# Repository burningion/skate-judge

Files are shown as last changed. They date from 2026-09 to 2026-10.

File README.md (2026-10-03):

# Judgy Skateboard

Record skateboard motion from an Adafruit LSM6DSO32 (accelerometer + gyro)
wired to an ESP32-S3 over STEMMA QT / Qwiic. Record webcam video in the web UI,
label makes, bails, and falls, and align webcam or phone footage using timestamped LED flashes.
The original live 3D orientation viewer is also included.

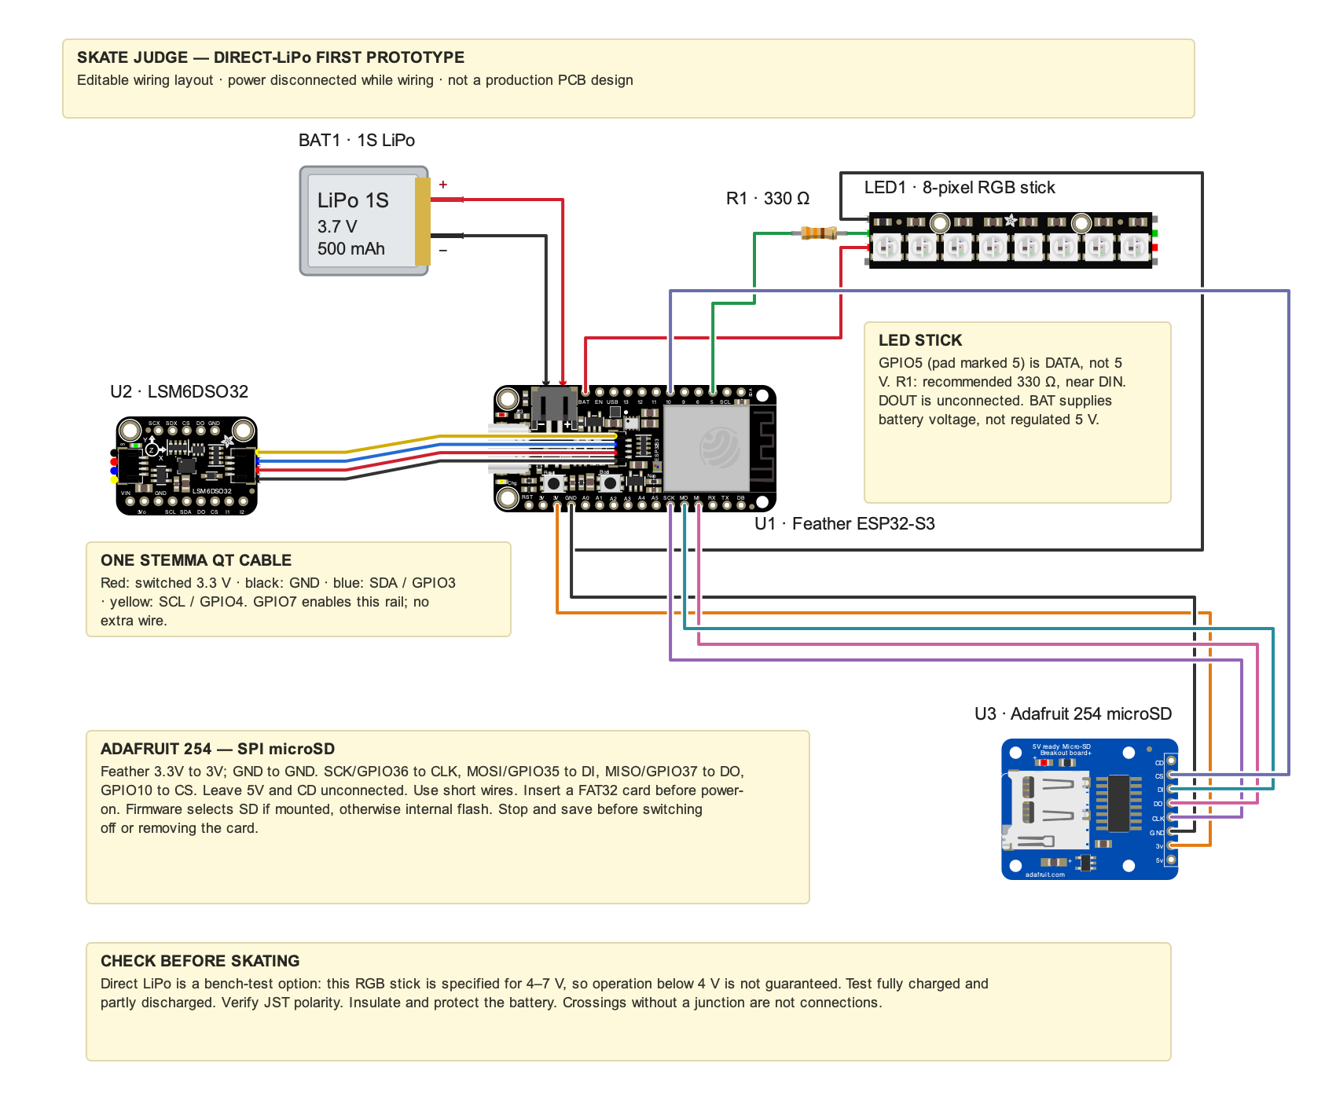
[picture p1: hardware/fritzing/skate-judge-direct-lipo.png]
hardware layout


This is the **data collection stage**: the review tool can suggest audio-based
pop/contact pairs for human review; it does not yet classify tricks, train
a model, or play automatic judgments. A board-mounted IMU measures the board's
motion, which does not always reveal whether the rider stayed on or fell.
Start with [your first dataset recording](docs/first-recording.md). The
[hardware and recording reference](docs/recording.md) covers wiring, file formats,
and the model plan.

[Research papers and reading notes](reference/README.md) cover skateboard IMU
trick recognition, landing-outcome limitations, and audio-feedback precedents.

```
firmware/imu_logger/   208 Hz sensor FIFO to SD or internal flash, timestamped LED sync
firmware/imu_stream/   legacy live stream for the orientation viewer
capture/onboard.py    onboard recording controls, verified download, recovery, CSV import
capture/session.py    recorder, human outcome labels, phone/video clock alignment
capture/dataset.py    collection progress and versioned datasets across reviewed sessions
capture/controls.html local webcam recording and countdown UI (--controls)
viz/imu_viz.py         pygame + OpenGL viewer: Mahony sensor fusion, calibration, 3D board with axes
viz/render_overlay.py transparent 3D skateboard + synchronized sensor/audio graphics for video editing
viz/trick_review.py    local video/audio review, onset pairs, editable boundaries, LED alignment
flash.sh               compile + upload with arduino-cli
flash-feather.sh        preset: Feather S3 8MB / no PSRAM, eight-pixel RGB stick on GPIO5
tests/                 sensor/video integrity, local HTTP, and webcam controller checks
```

## Your hardware and pinout

An [editable Fritzing wiring project](hardware/fritzing/README.md) is included,
with bundled parts and a preview of the direct-LiPo prototype.

A [parametric OpenSCAD enclosure](hardware/enclosure/README.md) includes PLA print
files, a screw-mounted deck base, a Velcro alternative, and a recessed LED mount
integrated into the enclosure's side.
Check the battery dimensions and mounting clearance before printing.

This setup uses the Adafruit Feather ESP32-S3 **8 MB flash / no PSRAM**, an
LSM6DSO32 IMU, a **3.7 V 500 mAh LiPo**, and an **eight-pixel SKC6812 RGB stick**.
For the first direct-LiPo bench test, wire with power disconnected:

| Connection | Destination |
| --- | --- |
| LiPo plug | Feather battery JST socket, with matching polarity |
| Feather `BAT` | Stick `5V` / `+` input |
| Feather `GND` | Stick `GND` |
| Feather header printed **5** (GPIO5) | Stick `DIN`, preferably through a 330 Ω resistor near `DIN` |
| Stick `DOUT` | Leave unconnected |
| Feather STEMMA QT socket | LSM6DSO32 STEMMA QT socket |

**The label “5” means GPIO5, not 5 volts or the fifth header position.**
The resistor is recommended protection on the data wire, not a strict requirement
or an LED brightness resistor. A short-wire bench test can omit it.

Adafruit documents direct LiPo power for short NeoPixel chains, but this stick's
listing specifies 4–7 V. Test visibility and correct colors as the battery runs
down before relying on it for sync; a regulated 5 V supply with a level shifter
is the fallback. See [power details and manufacturer sources](docs/recording.md#direct-lipo-wiring-for-the-first-test).

## First dataset recording

Flash the onboard logger, then initialize its unused storage once over USB:

```bash
./flash-feather.sh
uv run capture/onboard.py --board serial:auto initialize
```

Initialization refuses to erase a nonblank, unrecognized partition. The logger
keeps the preset's existing 1.5 MiB data partition; it does not repartition flash.

For battery operation, join **SkateJudge-XXXX** (password **skate-judge**), then:

```bash
uv run --offline capture/onboard.py record --rider rider-01 --board-name deck-01
```

Open the printed localhost URL. Enable microphone audio if you want audio onset
suggestions. **Record video + sync** starts webcam recording, waits for video
bytes to reach the laptop, starts onboard motion recording, checks its measured
rate, and only then begins the three-second LED countdown.

Acceleration and rotation use **nominal 208 Hz** acquisition through the sensor FIFO and are
saved on the **SD card when available**, with internal flash as the fallback
selected at boot. The page shows the storage destination, actual rates, errors,
and free space. The tested sensor measures about 196.5 Hz, consistent with its
factory clock calibration. Wi-Fi carries commands and status during capture; losing the connection
does not stop motion logging. Download happens after acquisition stops.

Repeat the sync countdown near the end, wait for the flash, then choose
**Stop & save video + board data**. Keep the tab and terminal open until both
are saved. The raw file is checksum-verified, imported into `samples.csv` and
`events.jsonl`, and retained on the board. Match the visible flashes in the
[review tool](docs/trick-review.md) to align video and motion.

Start with **one-minute test batches**. If using internal flash, its existing
partition holds only minutes; SD provides more capacity. Download and verify
each batch, then explicitly delete its onboard copy to reclaim space. See the
[first recording guide](docs/first-recording.md)
and [onboard storage/recovery reference](docs/onboard-recording.md).

For a USB bench check, use `--board serial:auto` before `record`. For a separate
phone camera, start that camera yourself and check the external-camera option
before syncing. Sessions are saved under `sessions/` and excluded from Git.

### Find and delete a test recording

Choose **Stop & save video + board data** and wait until saving finishes. The
terminal prints `Session: ...`, which is the laptop folder for that run. To
choose an easy-to-find folder before a USB test, use:

```bash
uv run --offline capture/onboard.py --board serial:auto record --output sessions/test-001
```

Use a new folder for each test. After saving, its `metadata.json` identifies the
run with `onboard_id`, its board storage with `onboard_storage` (`sd` or `flash`),
and its downloaded raw file with `onboard_raw_file`. The folder also contains
`samples.csv`, `events.jsonl`, and any video recorded through the webcam UI.

To inspect the board over USB, quit the saved recorder first to release the
serial port, then run these commands from the repository directory:

```bash
uv run --offline capture/onboard.py --board serial:auto status
uv run --offline capture/onboard.py --board serial:auto list
```

`status` shows the current storage destination in `storage` and remaining space
in `free_bytes`. `list` shows each saved run's `id`, `storage`, and `bytes` across
both mounted media. Match the ID to your session's `metadata.json`; the list is
not sorted by recording time. SD originals live at `/skate-judge/<id>.bin` on
the card. Downloading leaves the original on the board.

To remove one board copy, replace `<id>` and `<session>` below with your run's
32-character ID and laptop folder. Use `--storage flash` instead if that run's
storage is `flash`:

```bash
uv run --offline capture/onboard.py --board serial:auto delete "<id>" --storage sd \
  --downloaded "sessions/<session>/onboard-<id>.bin"
uv run --offline capture/onboard.py --board serial:auto list
```

The single-run `delete` command requires a downloaded raw file with a matching
ID and checksum. If you have not downloaded the run, retrieve it into a new folder first:

```bash
uv run --offline capture/onboard.py --board serial:auto download "<id>" --storage sd \
  --output sessions/recovered-test-001
```

Then use that folder's `onboard-<id>.bin` for `--downloaded`. To discard the
entire test, delete the board copy first, then move its laptop session folder
to Trash in Finder. Board deletion leaves the laptop files in place; deleting
the laptop folder alone does not reclaim board storage.

For Wi-Fi, join **SkateJudge-XXXX** and omit `--board serial:auto` from these
commands. The standalone `test-led` command creates no recording to clean up.

### Wipe all board recordings in one command

Stop any recording and quit the USB recorder, then run:

```bash
uv run --offline capture/onboard.py --board serial:auto wipe --yes
```

This permanently deletes **all recordings on both mounted SD and internal
flash**, including runs you have never downloaded. No download is required.
Laptop session folders, other SD card files, firmware, Wi-Fi credentials, and
pin settings are kept. The command works with the current logger firmware;
no reflash is needed.

Add `--storage sd` or `--storage flash` to clear only that medium. For Wi-Fi,
join **SkateJudge-XXXX** and omit `--board serial:auto`. `--yes` is required to
confirm deletion. The board must be idle; the command never stops a recording
for you. It reports each deletion and checks that the selected storage is empty
of recordings. If interrupted, rerun it to clear the remaining files. Storage
that is not mounted cannot be wiped.

## Review a recorded trick

The [audio/video review guide](docs/trick-review.md) explains onset detection,
editable pop/contact boundaries, and matching LED flashes to the sensor clock.
With FFmpeg installed, run:

```bash
uv run viz/trick_review.py sessions/<session>/webcam-<id>.webm
```

Open the printed local URL, match the LED flashes, then label attempts in the
same page. Choose the trick and outcome, or **Not a trick** for an onset false
positive; saving advances to the next suggestion. Labels save to `labels.jsonl`
with aligned sensor times. **Download saved labels** exports this clip's current
labels. Audio suggestions and unreviewed time remain unlabeled until you decide.

## Accumulate labeled sessions

Each session keeps its raw recordings and saved labels. After finishing or
correcting labels (for example, in `sessions/a7s-018`), run these commands from
the repository root to refresh the combined dataset from **all labeled
`sessions/a7s-*` directories**:

```bash
python3 capture/dataset.py status --labeled-only --allow-sample-gaps a7s-018
python3 capture/dataset.py build --labeled-only --allow-sample-gaps a7s-018 \
  --output datasets/a7s-v3
```

Choose an unused version directory each time (`a7s-v4`, `a7s-v5`, and so on).
Existing snapshots are immutable; saving labels does not refresh them. There is
no need to download or manually merge labels from the review UI.

`--labeled-only` skips sessions with missing or empty `labels.jsonl`, so unfinished
unlabeled recordings do not block the refresh. Omit it from `status` to inventory
every session. Labeled sessions still receive all alignment and sensor quality
checks; unreadable labeled sessions block the build.

`--allow-sample-gaps a7s-018` includes this complete recording despite its
`sample_gaps_over_10ms` flag: ten sample intervals were 10.1–10.5 ms, while
the typical interval was about 5.1 ms. Repeat this option on future refreshes
to keep including it. This exception applies only to the named session, only
when that is its sole onboard quality issue, and still excludes individual
windows with gaps over 30 ms, clipping, or other eligibility failures. The
source quality flag is retained; the report and manifest record the exception.
Omit the option for the original strict session policy. See the
[dataset guide](docs/dataset.md#accepting-a-session-with-small-sample-gaps) for details.

Check the printed counts and exclusions, then inspect the new snapshot's
`report.json` and `manifest.jsonl`. The manifest includes the latest revision of
every saved label and any exclusion reasons; `samples.csv` contains only eligible
IMU windows with session/rider IDs in the manifest. A saved label can be excluded
by a recording quality flag, stale alignment, or a bad sensor window. Investigate
these issues before using excluded labels for training; the export does not clear
quality flags.

See [dataset collection and export](docs/dataset.md) for exclusions, file formats,
and how to plan the first 100 attempts. Sessions and exports are local and
excluded from Git; back up the original session directories separately.

## One-time setup

```bash
brew install arduino-cli uv
arduino-cli core install esp32:esp32 --additional-urls https://espressif.github.io/arduino-esp32/package_esp32_index.json
```

The Adafruit LSM6DS library (plus BusIO and Unified Sensor) is installed into
`./.arduino` the first time `flash.sh` runs. NeoPixel builds also install
Adafruit NeoPixel there, so nothing touches your global Arduino sketchbook.

## Flash the board

For onboard capture with this Feather, use `./flash-feather.sh`. The generic
`./flash.sh` defaults to the legacy stream sketch used by the viewer.

Both scripts accept `--compile-only` to build without uploading.

The generic script builds for the `esp32s3` target with USB CDC on boot, so it
talks over the ESP32-S3's native USB port. It probes the usual STEMMA QT pin
pairs at startup and, for Adafruit Feathers, switches on the I2C power rail
first. It prints what it found:

```
I,LSM6DSO32 at 0x6A on SDA=3 SCL=4 (Adafruit Feather ESP32-S3 / Reverse TFT, I2C power on GPIO 7)
```

To try specific pins first: `IMU_SDA=3 IMU_SCL=4 IMU_POWER=7 ./flash.sh`.

For your **Adafruit Feather ESP32-S3, 8 MB flash / no PSRAM**, connect the
eight-pixel SKC6812 RGB stick's data circuit to the header marked **5** (GPIO5).
The preset selects the board, IMU wiring, Wi-Fi, and all eight pixels:

```bash
./flash-feather.sh --compile-only  # build first
./flash-feather.sh                 # upload once connected
```

All eight pixels flash white for 150 ms on `sync`, then turn off. Brightness
defaults to the maximum 255/255; override with `SYNC_LED_BRIGHTNESS`. For an RGBW stick,
use `SYNC_LED_RGBW=1 ./flash-feather.sh`.
See [stick wiring and power](docs/recording.md#eight-pixel-neopixel-stick)
before connecting it. Direct-LiPo wiring uses `BAT`; the Feather's `USB` pin
only supplies 5 V while USB is connected.

## Export transparent graphics for editing

After saving trick labels and matching the LED flashes, render a 3D skateboard
with synchronized onset, accelerometer, and gyroscope graphics:

```bash
uv run viz/render_overlay.py sessions/a7s-001 --video C0642.MP4 \
  --nose-axis x --up-axis=-z --width 1080 --height 1920
```

This writes one vertical transparent ProRes 4444 clip per attempt and PNG previews.
Add `--reel` for a combined reel.
If the board was level and still at every matched flash, add `--flat-syncs`
to use those moments as tilt and gyro-bias calibration references.
See [transparent overlays](docs/transparent-overlays.md) for slow motion,
mounting controls, timing, and editing instructions.

For isolated images comparing makes and bails, run
`uv run viz/plot_attempts.py sessions/a7s-001 --video C0642.MP4`.
This exports comparison sheets and one detailed PNG per attempt to
`sessions/a7s-001/plots/C0642-pop-contact/`, using shared scales and saved
pop/contact markers. Each detailed image includes accelerometer and gyro
magnitudes plus raw X/Y/Z traces.

## Run the viewer

The orientation viewer requires the legacy stream firmware. Switch explicitly:

```bash
SKETCH=firmware/imu_stream ./flash-feather.sh
```

Return to `./flash-feather.sh` and `capture/onboard.py` for onboard dataset capture.

```bash
uv run viz/imu_viz.py
```

The port is auto-detected; pass `-p /dev/cu.usbmodem101` to pick one, or
`--demo` to run without hardware. Keep the board still for the first two
seconds while the gyro bias is measured.

| Key | Action |
|-----|---|
| C | re-calibrate the gyro bias (hold the board still) |
| Z | zero the heading (yaw) |
| M | toggle fused (gyro + accel) and tilt-only (accel) modes |
| R | reset the filter, peaks, and clip counters |
| S | save a screenshot |
| drag / wheel | orbit / zoom the camera |
| Esc | quit |

Because the LSM6DSO32 has no magnetometer, heading (yaw) is integrated from the
gyro and slowly drifts; roll and pitch are pinned by gravity and do not. Press
`Z` whenever you want the heading re-zeroed.

The firmware runs the accelerometer at ±32 g and the gyro at ±2000 dps (about
2294 dps before the 16-bit readings actually saturate), so deck landings and
fast flips stay in range. The HUD shows the peak accel and gyro seen so far
against those limits, counts samples that reached full scale, and flashes a red
`CLIPPING` warning when one does. Press `R` to reset the peaks and counters.

## Serial protocol

One line per sample, targeted at 100 per second, accel in m/s^2 and gyro in rad/s:

```
D,<device_us>,<ax>,<ay>,<az>,<gx>,<gy>,<gz>,<temp_C>,<sequence>,<boot_id>
```

`device_us` is the 64-bit monotonic microsecond clock since boot. The sample
sequence is an unsigned 32-bit counter; the random eight-character hex boot ID
changes on reset. The viewer accepts these trailing fields. The recorder also
accepts the original nine-field format and unwraps its 32-bit microsecond clock.

At startup the board also prints `R,<accel_sat_ms2>,<gyro_sat_rads>`, the values
at which its raw readings saturate, which the viewer uses for its clipping
check. `I,...` lines are informational, `E,...` lines are errors. Sending `i`
asks the board to repeat its info lines.

Sending `s` requests a 150 ms pulse. Both LED edges produce:

```
S,<device_us>,<sync_id>,<edge>,<led_enabled>,<boot_id>
```

`edge=1` is the rising edge; `edge=0` is the falling edge. `led_enabled=0`
means only an event was recorded, with no physical flash. Each timestamp is taken
immediately before its LED write; it approximates the physical edge time.

With Wi-Fi enabled, UDP port 5050 accepts single-byte commands `i`, `?`, `s`,
and `k` (heartbeat). A recorder acquires a five-second lease by sending one
of these; packets go back to that client's address and port. The recorder
renews every two seconds. One client owns the lease at a time. UDP can lose
packets; sequence gaps and timing gaps are saved for quality review.

## Checks

```bash
python3 -m unittest discover -s tests -v
node --test tests/test_webcam.mjs tests/test_trick_review.mjs tests/test_storage.mjs tests/test_battery.mjs
./flash-feather.sh --compile-only
./flash.sh --compile-only
SKATE_WIFI=1 ./flash.sh --compile-only
```

## Troubleshooting

- **No `/dev/cu.usbmodem*` after plugging in.** On Apple Silicon a new accessory
  first needs the "Allow accessory to connect" approval. Other apps that open
  every USB device (Chrome's WebUSB, Spotify) can also grab the port before the
  serial driver does; unplugging and replugging the board usually fixes it.
- **`./flash.sh` fails while "Connecting..."** The reset into the bootloader can
  re-enumerate the USB device and kill the port node; the script already retries
  once, otherwise replug and rerun.
- **`E,no LSM6DSO32 found`** Check the STEMMA QT cable, and if your board is not
  in the sketch's candidate table, pass the pins explicitly with `IMU_SDA` /
  `IMU_SCL` (and `IMU_POWER` if the port has a power-enable pin).

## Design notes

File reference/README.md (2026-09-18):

# Skateboard IMU research

Selected for **Judgy Skateboard**: a board-mounted accelerometer and gyroscope,
video-reviewed landed/failed attempts, and eventual spoken feedback after a
missed trick. Sources and download availability checked **2026-09-18**.

The closest hardware match is **Groh et al. (2015)**. Read its **2017 follow-up**
for failed attempts and false event detections, **Anlauff et al. (2010)** for
skateboard-triggered audio, and **Scholz et al. (2026)** for independent validation.

The central distinction is between **detecting an attempt**, **naming the trick**,
and **judging whether the rider landed and maintained control**. The reported
trick-recognition scores below do not establish make/bail/fall accuracy for this
project. In particular, an impact can locate board contact without proving that
the rider stayed on.

## Reading list and local copies

| Priority | Paper | Why it matters here | Copy |
| --- | --- | --- | --- |
| 1 | Groh et al., 2015 | Board-mounted six-axis IMU at 200 Hz; event detection and simple classifiers | [PDF](groh-2015-imu-based-trick-classification.pdf) |
| 2 | Groh et al., 2017 | Larger study includes incorrect attempts, bails, and false detections | Reference below; no public full PDF verified |
| 3 | Anlauff et al., 2010 | Real skateboard controls a game with audio feedback | Public author PDF linked below; download timed out |
| 4 | Scholz et al., 2026 | Independent field validation; exposes the gap between event detection and trick classification | [PDF](scholz-2026-skateboard-imu-validation.pdf) |
| 5 | Abdullah et al., 2021 | IMU signal classification with published data and code | Open-access links below; download unavailable from this environment |
| 6 | Ibrahim et al., 2020 | Small, interpretable feature-based baseline | Public university PDF linked below; download timed out |
| 7 | Corrêa et al., 2017 | Accelerometer-only neural-network approach, evaluated on synthetic signals | [PDF](correa-2017-accelerometry-machine-learning.pdf) |

The three saved PDFs are unmodified source files. Their original copyright and
license notices remain in the documents. A missing local copy does not necessarily
mean a paper is paywalled: the table distinguishes missing public full text from
download failures.

## 1. IMU-based Trick Classification in Skateboarding

**Benjamin H. Groh, Thomas Kautz, Dominik Schuldhaus, and Bjoern M. Eskofier.
2015.** KDD Workshop on Large-Scale Sports Analytics, Sydney, Australia.

[Local PDF](groh-2015-imu-based-trick-classification.pdf) ·
[University-hosted source PDF](https://www5.cs.fau.de/Forschung/Publikationen/2015/Groh15-ITC.pdf) ·
[Author's publication list](https://www.mad.tf.fau.de/person/benjamin-groh/)

- **Setup:** Board-mounted accelerometer/gyroscope at 200 Hz, ±16 g and
  ±2000 degrees/s; seven skateboarders, six tricks, and video/expert annotations.
  Our nominal 208 Hz logger is similar, with a wider ±32 g range.
- **Method:** Acceleration-energy thresholds locate impacts. Features span one
  second before through half a second after contact; several simple classifiers
  predict trick identity.
- **Evidence:** 94.2% event sensitivity and 97.8% best classification accuracy with
  leave-one-subject-out evaluation. Classification excluded false event detections;
  that score measures trick identity, not landing outcome.
- **Use here:** Sections 2.3–2.6 provide an event/feature baseline. Record mounting
  axes and stance: their preprocessing normalizes regular/goofy signals.

## 2. Classification and visualization of skateboard tricks using wearable sensors

**Benjamin H. Groh, Martin Fleckenstein, Thomas Kautz, and Bjoern M. Eskofier.
2017.** *Pervasive and Mobile Computing* **40**, 42–55.
DOI: [10.1016/j.pmcj.2017.05.007](https://doi.org/10.1016/j.pmcj.2017.05.007).

[Publisher article and preview](https://www.sciencedirect.com/science/article/pii/S1574119217302833)

- **Setup:** One skateboard-mounted inertial–magnetic unit; 11 skateboarders,
  11 tricks, and 905 performances, including correct and incorrect executions
  and bails.
- **Evidence:** The event detector found 872 of 905 attempts, with 431 false
  detections: 96.4% recall and 66.9% precision. Subsequent classification includes
  a rest class to reject non-trick events. The advertised 89.1% trick-classification
  accuracy concerns correctly performed tricks.
- **Use here:** This is the strongest match for collecting failures and background
  alongside makes. It illustrates why a high-recall impact detector needs a second
  stage before triggering a roast. The reported recognition result does not tell
  us how accurately our make/bail/fall labels can be predicted.
- **Limit/access:** Its nine-axis hardware includes a magnetometer that our
  LSM6DSO32 lacks. These notes use the publicly available abstract and preview;
  no public complete PDF was verified. The publisher offers institutional access
  or PDF purchase.

## 3. A Method for Outdoor Skateboarding Video Games

**Jan Anlauff, Erik Weitnauer, Alexander Lehnhardt, Stefanie Schirmer,
Sebastian Zehe, and Keywan Tonekaboni. 2010.** *Proceedings of the 7th International
Conference on Advances in Computer Entertainment Technology (ACE '10)*, 40–44.
DOI: [10.1145/1971630.1971642](https://doi.org/10.1145/1971630.1971642).

[Public author PDF at Bielefeld University](https://www.techfak.uni-bielefeld.de/ags/ami/publications/media/AnlauffWeitnauerLehnhardtSchirmerZeheTonekaboni2010-AMF.pdf)

- **Setup:** The Tilt'n'Roll prototype connects a sensor-equipped real skateboard
  to a mobile game. It collects acceleration, angular velocity, and foot-pressure
  information at approximately 70 Hz, and uses linear discriminant analysis for
  Ollie, Ollie 180, and a no-trick class.
- **Use here:** An unusually close precedent for the product idea: detected tricks
  drive game events, and the rider receives progress information through audio.
  Its pressure channel is also relevant if board motion alone proves ambiguous
  about whether the rider is still aboard.
- **Limit/access:** Its extra pressure sensors and small trick vocabulary differ
  from our setup; it does not validate make/bail/fall classification. The public
  author copy is indexed, but university and publisher downloads timed out here.

## 4. Validity of a Commercially Available Inertial Measurement Unit for Artificial Intelligence-Based Trick Detection and Kinematic Performance Assessment in Skateboarding

**Birte Scholz, Niklas Noth, Maren Witt, and Olaf Ueberschär. 2026.**
*Sensors* **26**(8), 2537.
DOI: [10.3390/s26082537](https://doi.org/10.3390/s26082537).

[Local PDF](scholz-2026-skateboard-imu-validation.pdf) ·
[Open-access article](https://www.mdpi.com/1424-8220/26/8/2537) ·
[Source PDF](https://mdpi-res.com/d_attachment/sensors/sensors-26-02537/article_deploy/sensors-26-02537.pdf)

- **Setup:** Independent Spinnax Freak validation with 23 skateboarders and
  reference measurements including video and light barriers.
- **Evidence:** Ollie/Kickflip event detection outperformed trick naming; airtime
  and other motion measurements showed substantial errors.
- **Critical limitation:** Section 2.3 explains that failed attempts were repeated
  or abandoned; all documented tricks were successfully landed. This does not
  validate bail/fall detection. The classifier is proprietary.
- **Use here:** Validate event detection, trick identity, and outcome separately
  against reviewed video before using a prediction to trigger audio.

## 5. The classification of skateboarding tricks via transfer learning pipelines

**Muhammad Amirul Abdullah, Muhammad Ar Rahim Ibrahim, Muhammad Nur Aiman
Shapiee, Muhammad Aizzat Zakaria, Mohd Azraai Mohd Razman, Rabiu Muazu Musa,
Noor Azuan Abu Osman, and Anwar P.P. Abdul Majeed. 2021.**
*PeerJ Computer Science* **7**, e680.
DOI: [10.7717/peerj-cs.680](https://doi.org/10.7717/peerj-cs.680).

[Open-access article](https://peerj.com/articles/cs-680/) ·
[PubMed Central full text](https://pmc.ncbi.nlm.nih.gov/articles/PMC8384043/) ·
[Publisher PDF](https://peerj.com/articles/cs-680.pdf) ·
[Code supplement](https://doi.org/10.7717/peerj-cs.680/supp-1) ·
[Dataset supplement](https://doi.org/10.7717/peerj-cs.680/supp-2)

- **Setup/method:** Six skateboarders perform five trick types. The six IMU
  channels become raw-signal images or continuous-wavelet-transform images;
  pretrained CNNs extract features for an optimized SVM. These are images of
  sensor signals, not camera frames.
- **Use here:** Compare learned representations with time-domain features. Raw
  data and code supplements support inspecting the collection format and
  reproducing a trick-identity baseline.
- **Limit/access:** Trick classes differ from our outcome classes. Check the data
  and evaluation splits before reuse; results do not establish failed-attempt
  recognition. Public PDF hosts timed out or blocked retrieval here. Supplements
  are linked, not imported into training sessions.

## 6. The Classification of Skateboarding Trick Manoeuvres: A K-Nearest Neighbour Approach

**Muhammad Ar Rahim Ibrahim, Muhammad Amirul Abdullah, Muhammad Nur Aiman
Shapiee, Mohd Azraai Mohd Razman, Rabiu Muazu Musa, Muhammad Aizzat Zakaria,
Noor Azuan Abu Osman, and Anwar P.P. Abdul Majeed. 2020.** In *Enhancing Health
and Sports Performance by Design*, Lecture Notes in Bioengineering, 341–347.
DOI: [10.1007/978-981-15-3270-2_36](https://doi.org/10.1007/978-981-15-3270-2_36).

[University repository record](https://umpir.ump.edu.my/id/eprint/33630/) ·
[Public PDF](https://umpir.ump.edu.my/id/eprint/33630/1/MAR1.pdf)

- **Setup/method:** One experienced amateur skateboarder performs five trick
  types on an IMU-equipped board. Features include mean, skewness, kurtosis,
  peak-to-peak, RMS, and standard deviation of acceleration and angular velocity.
  The best tested kNN configuration achieved 85% trick-classification accuracy.
- **Use here:** A compact feature list for an inexpensive first baseline before
  trying larger neural models.
- **Limit/access:** A single-rider preliminary study cannot establish generalization
  across riders, boards, or surfaces, and its target is trick identity. The
  university advertises a public PDF, but its download host timed out here.

## 7. Development of a skateboarding trick classifier using accelerometry and machine learning

**Nicholas Kluge Corrêa, Júlio César Marques de Lima, Thais Russomano, and
Marlise Araujo dos Santos. 2017.** *Research on Biomedical Engineering*
**33**(4), 362–369.
DOI: [10.1590/2446-4740.04717](https://doi.org/10.1590/2446-4740.04717).

[Local PDF](correa-2017-accelerometry-machine-learning.pdf) ·
[Journal record](https://www.rbejournal.periodikos.com.br/article/doi/10.1590/2446-4740.04717) ·
[arXiv record](https://arxiv.org/abs/2005.04186) ·
[Source PDF via arXiv export](https://export.arxiv.org/pdf/2005.04186)

- **Method:** Feed-forward neural networks classify five trick types using
  modeled acceleration signatures, with separate networks for individual axes.
- **Critical limitation:** The study uses **543 artificial axis signals representing
  181 simulated tricks**, not a dataset of 543 real attempts. Its reported scores
  therefore do not demonstrate recognition of actual makes, bails, or falls.
- **Use here:** Background on accelerometer signatures, preprocessing, and an
  accelerometer-only comparison. Prioritize real, reviewed recordings for our
  outcome model. Retaining gyro channels also allows an accelerometer-only versus
  six-axis comparison on the same held-out sessions.
- **Version:** The journal paper is from 2017; its arXiv deposit is from 2020.
  The downloaded PDF contains the journal article and its CC BY notice.

## Implications for this repo

These are proposed experiments, not claims that the papers validated our model.
They align with the existing [model plan](../docs/recording.md) and
[video-labeling workflow](../docs/trick-review.md).

1. **Keep outcome and trick identity separate.** Preserve `make`, `bail`, `fall`,
   `unknown`, and `background`. A binary landed/not-landed target can later map
   `make` versus `bail`/`fall`; do not silently map unknown or background to a miss.
2. **Keep the roll-away.** Pop/contact markers locate the action, while the full
   attempt window must include enough aftermath to judge control. Compare contact
   windows with windows that include post-contact motion.
3. **Measure the whole trigger pipeline.** Evaluate missed attempts and false
   roasts during continuous skating, including pushing, carrying, dropping the
   board, and ordinary rolling. Report outcome precision/recall, false triggers
   per minute, and delay after the outcome.
4. **Hold out sessions and riders.** Avoid mixing neighboring windows from one
   recording across training and test sets. Preserve mounting orientation, board,
   stance, surface, and sensor-quality metadata to investigate errors.
5. **Start with a small baseline and an uncertain result.** Compare simple
   acceleration/gyro features before heavier models. Tune the failure threshold
   and cooldown on validation sessions; ambiguous board motion should be allowed
   to produce no audio response.

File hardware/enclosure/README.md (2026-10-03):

# PLA enclosure for Judgy Skateboard

Open **[skate-judge.scad](skate-judge.scad)** in **OpenSCAD 2021.01 or newer**.
This is a printable prototype for the project's Feather ESP32-S3, LSM6DSO32,
500 mAh LiPo, Adafruit 254 microSD breakout and an eight-pixel sync stick mounted
**inside the long side wall**.
It needs a physical fit check
and progressive riding trials; CAD checks do not establish impact survival.

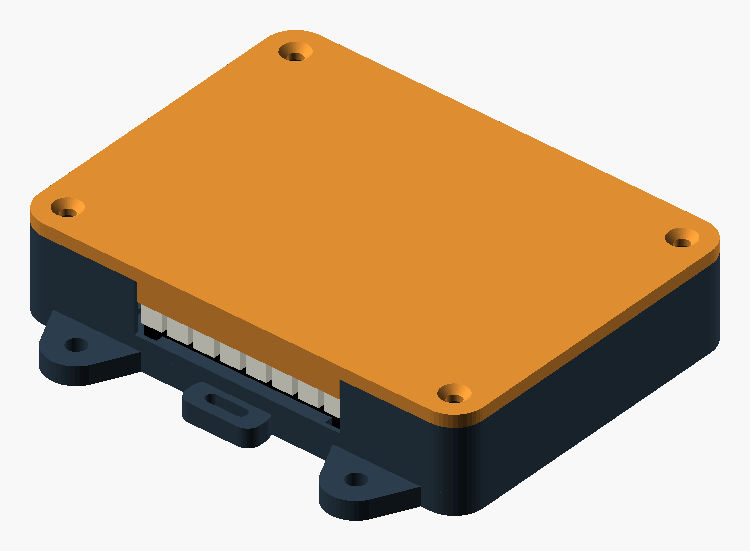
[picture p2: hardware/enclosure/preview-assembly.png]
Enclosure with recessed side-facing LEDs


**Revision 8 — 2026-10-03, heat-set inserts for the lid.** Both bases now use
four top-loaded **M3 × 4 × 5 mm inserts** in place of the side-loaded hex nuts.
The user confirmed the Jouth size as **M3 thread, 4 mm length,
5 mm outside diameter**. A Jouth recommended hole size was not available;
check the printed fit with the coupon before printing the base.
The starting bore is **4.6 mm diameter × 5 mm deep**, with a **0.2 mm entry bevel**
opening to 5.0 mm. Install inserts flush with the boss tops. The existing 12 mm
boss diameter leaves 3.5 mm of plastic radially around a 5 mm insert; the side
nut channels are filled in. A **3.4 mm screw-tip clearance bore extends 10 mm
below the boss top**, so existing M3 × 12 mm countersunk screws retain nominal
1 mm tip clearance with the 3 mm lid. M3 × 8 mm screws also reach the full insert.

**Reprint only the base**: [standard base](exports/base.stl) or
[Velcro base](exports/base-velcro.stl). The lid geometry and hole centers are
unchanged. Print the revised **[fit coupon](exports/fit-coupon.stl)** first:
its three full-height bosses have labeled **4.4 / 4.6 / 4.8 mm** insert bores,
the same depth, bevel and screw relief as the base, and separate M2 pilot tests.
Use the same filament, orientation and wall settings as the base. Choose the
fit that heat-sets squarely and holds without splitting or spinning after cooling;
change `lid_insert_bore_diameter` and rebuild if the center bore is not the best
fit. A CAD clearance check does not establish heat-set retention.

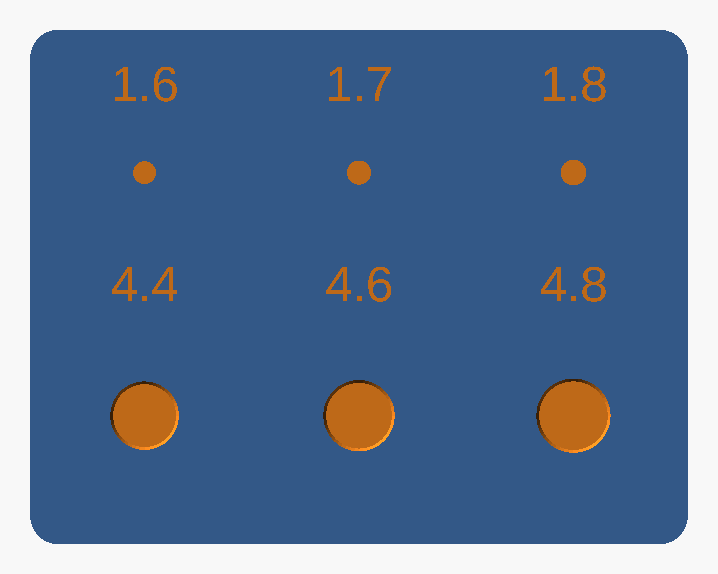
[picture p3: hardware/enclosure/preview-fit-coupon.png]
Insert bore and M2 pilot fit coupon


**Revision 7 — 2026-10-02, power-switch cutout beside USB.** Both bases now
have a **13.5 mm wide × 8.4 mm high** rectangular opening in the **x=0 short
wall**, on the same side as USB. This uses the measured **13.27 × 8.18 mm**
KCD11-101 style switch body with **0.23 × 0.22 mm total clearance**; no further
fit allowance is added. The opening is centered at **Y=50, Z=11.5 mm**, spanning
Y=43.25–56.75 and Z=7.3–15.7 mm. It leaves **7.82 mm of wall between the USB
and switch openings**, and 4.3 mm of material above and below the opening
between the floor and rim. **Only the base needs reprinting**; use the refreshed
[base](exports/base.stl) or [Velcro base](exports/base-velcro.stl). The lid still fits.

The switch inserts through the existing **3 mm wall**. Check the actual snap
clips, bezel, body depth, terminals and insulated wire bends against the battery
tray/strap anchor before assembly; only the supplied body cross-section is known.
The cutout adds a **13.5 mm roof bridge** to the base, so inspect that bridge in
the slicer and check the printed opening with your switch.

**Revision 6 — 2026-09-26, preserve the installed IMU orientation.** The user
confirmed that the IMU extends from its two screws toward the SD board, with
components facing the lid. In that orientation, the old screw positions put
the IMU into the SD mounting posts. R6 moves both IMU posts **12.7 mm toward
the LED window**: centers are now **(76.54, 19.54)** and **(96.86, 19.54)**,
instead of Y=32.24. Slide the physical IMU toward the LEDs without turning it.
Its two screws now sit on the LED side of its PCB; the PCB extends toward SD.
This corrects the previous drawing's orientation assumption.

The IMU posts remain **4 mm high** and the SD posts **7 mm high** above the
floor. There is **4.22 mm nominal separation between the PCB outlines**.
Changing heights is unnecessary; lowering SD would reduce the card-removal
clearance above the battery. **Only the base needs reprinting**; the lid and
SD mounting sample are unchanged. Use the refreshed [base](exports/base.stl)
or [Velcro base](exports/base-velcro.stl). The current R8 exports retain this layout.

Existing recordings remain in their original sensor axes. Keeping the same
physical orientation avoids a new axis mapping, but translating the sensor can
change the acceleration measured during rotations. Record the R6 mount revision
and 12.7 mm position shift alongside subsequent sessions; do not overwrite old
session mounting descriptions or rotate their raw samples to match a CAD image.
If the sensor is physically rotated in a future revision, retain the originals
and apply the measured sensor-to-deck rotation to both acceleration and gyro
during analysis. The existing overlay tools support explicit nose/up axis mapping.

**Revision 5 — 2026-09-26, screw-mounted microSD breakout.** Four 7 mm-high posts
secure the Adafruit 254 board beside the battery, with a separate wire tie point.
The enclosure dimensions stay the same. **Reprint only the base if you already
have an R3/R4 lid**; the R4 lid geometry is unchanged. The SD card slides toward
the battery for removal with the lid off. Its path is raised above the assumed
5 mm-thick cell; keep the battery strap and wires out of that path.

Print the [SD mounting sample](exports/sd-fit-base.stl) first to check all four
holes and your screws. It is **33.75 × 27.4 × 10 mm**, with the same post heights
and pilots as the full base. Use four **M2 × 5 mm screws suitable for plastic**,
with heads no larger than **4 mm diameter × 2 mm high**. This is for the
Adafruit 254 hole pattern (20.32 mm square); check your actual board against it.
The sample checks mounting fit, not the complete wiring or card-removal path.

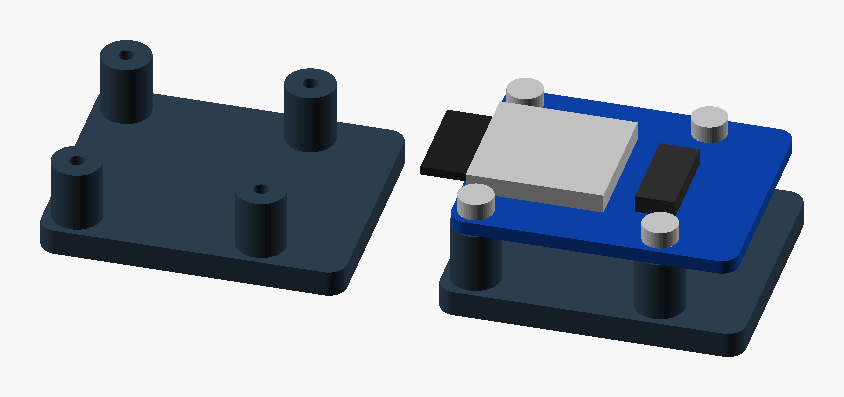
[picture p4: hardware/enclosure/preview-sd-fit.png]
MicroSD mounting posts and compact fit sample


**Revision 4 — 2026-09-15, DIN 7991 M3 flat-head lid screws.** All four lid holes
now have a **6.4 mm exterior opening, 90° included bevel and 1.5 mm recess depth**,
with the existing 3.4 mm shaft clearance. This leaves 1.5 mm of the 3 mm lid
beneath each bevel. DIN 7991 M3 heads are 6 mm across with a 90° bevel
([supplier drawing](https://belmetric.com/content/A-PDF_Drawings/SF3X6SS.pdf));
the opening adds 0.4 mm of diameter for printed fit. Check seating with your
actual screws; diameter and angle remain adjustable. The R4 lid fits the R3
base, so only the lid needs reprinting for this change.

**Revision 3 — 2026-09-08, fixes from the first physical print.** The previous
lid preview reflected the printed part instead of rotating it into place. This
hid the reversed position of its asymmetric wall-closing tabs. The lid STL now
accounts for the physical flip; neither the preview nor the fit check reflects
the printed lid into place.

The LED PCB slides down into a channel from the open top. The screwed-on lid
retains it; the eight pixels face outward through a recessed side opening.
Both ends now have actual **open-top through-slots for soldered leads**. Rear
guides are moved away from the solder zones, and the lid locates the PCB's
unsoldered upper corners. It leaves 0.8 mm above the board instead of 0.3 mm.

Print the [LED fit sample base](exports/led-fit-base.stl) and
[matching sample lid](exports/led-fit-lid.stl) first, and try your **soldered**
stick. These reproduce the entire holder and its lid features in a
**63.1 × 13 mm footprint**; hold the lid seated by hand. They do not test the
USB tab or full enclosure screw alignment. When upgrading from R2, print **both
the revised full base and lid**. R3/R4 lid corner locators occupy the old end-stop
positions; do not mix R3/R4 parts with the unmodified R2 base/lid.

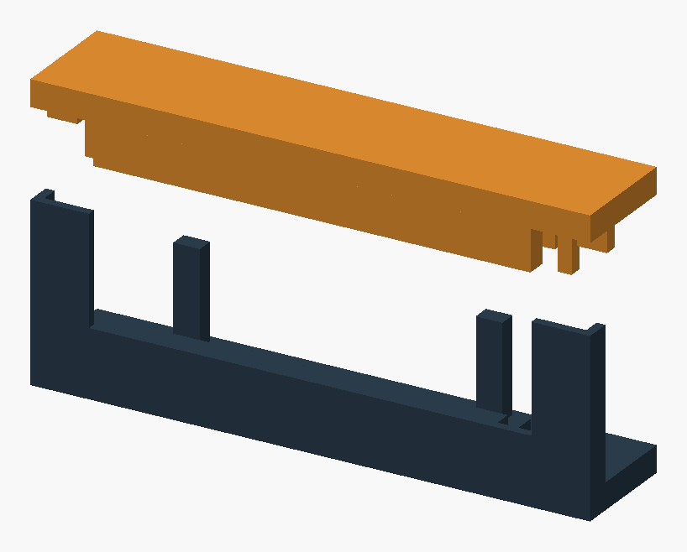
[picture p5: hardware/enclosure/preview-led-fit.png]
Small LED holder and matching lid test pieces


## Mounting choice

**Use a rigid deck mount for motion recording.** The default base has four broad
4.5 mm-thick lugs with 4.5 mm clearance holes, a flat deck-facing back, and two
tether slots. The lid faces away from the deck and is removable while mounted.
Nominal shell dimensions are **108 × 80 × 23 mm**, excluding screw heads;
the lugs increase the footprint to **108 × 106 mm**. Place its long axis along
the deck, inboard of a truck, with the LED side facing the camera and clearance
checked on your actual board. Confirm that the deck overhang does not hide the
LEDs at the intended camera height; a side window alone does not establish visibility.
No deck curvature, truck geometry, or wheel sweep was supplied.

| Attachment | Use with this model |
| --- | --- |
| Deck screws/bolts | Preferred for rigid IMU coupling. Four M4 through-bolts, washers and locking nuts through suitable deck holes and the lugs. Hole centers form a 68 × 92 mm rectangle. Choose length for the measured deck, 4.5 mm lugs, washers and full nut engagement. This is a new mounting pattern, **not truck-bolt spacing**. |
| Adhesive hook-and-loop | Use `base-velcro.stl` or the standard base. Its flat back accepts two roughly 20 × 60 mm strips. The earless version is 108 × 94 mm including tether lugs. Use a secondary tether; check tape compatibility with the deck finish and leave tether slots clear. Hook-and-loop compliance can introduce motion artifacts, so compare a recording against a rigid mount. |
| PLA truck snap | Not selected. A stressed snap is a poor match for brittle PLA under repeated skate impacts. The hanger also steers relative to the deck. A future truck adapter should attach to the fixed baseplate using measured geometry and appropriate hardware, and use a tougher material; this design does not alter truck hardware or add a PLA riser to that joint. |

The PLA decision is an engineering judgment based on [Prusa's material guidance](https://help.prusa3d.com/article/pla_2062): PLA is brittle, has weak impact/layer resistance,
and can deform above about 60 °C. This enclosure uses thick walls and broad lugs,
with no spring clips or constantly flexed latches. Keep it out of hot cars and
direct heat. For a durable riding version, reconsider the material and validate
the printed parts rather than relying on PLA geometry alone.

Do not use ordinary short wood screws as an assumed universal skate-deck mounting
solution: the deck thickness, condition, screw penetration and placement need to
be checked first. Do not compromise existing truck holes or crush the deck with
fasteners. Match a curved deck using fitted **rigid** shims under the lugs; do not
pull a flat enclosure into the concave with screw torque. The flat Velcro back
likewise needs enough actual contact area on your deck.

## Parts to print

| STL | Quantity | Print orientation |
| --- | --- | --- |
| [base.stl](exports/base.stl) | 1 | Flat deck-facing back on bed, cavity up |
| [base-velcro.stl](exports/base-velcro.stl) | Alternative to base | Same; ears omitted, tether lugs retained |
| [lid.stl](exports/lid.stl) | 1 | Flat exterior face on bed, guide ribs up |
| [fit-coupon.stl](exports/fit-coupon.stl) | 1 first | Flat back on bed, insert bosses upward; 46 × 36 × 20 mm |
| [led-fit-base.stl](exports/led-fit-base.stl) | 1 first | Flat bottom on bed, slot upward |
| [led-fit-lid.stl](exports/led-fit-lid.stl) | 1 first | Flat exterior on bed, tabs upward |
| [sd-fit-base.stl](exports/sd-fit-base.stl) | 1 first | Flat bottom on bed, posts upward |

Exported files already have those orientations and use millimeters. The LED mount
fits inside the existing shell footprint. `layout` is for visual inspection;
arrange individual STLs for your printer's bed.
Do not print `assembly` or `exploded`: those views include illustrative electronics.

Start with a 0.4 mm nozzle, 0.20 mm layers, **5 perimeters**, 6 top/bottom layers,
and 35–45% gyroid infill. Use solid local infill around lugs, lid bosses and PCB
posts if the slicer leaves voids there. Use your filament's calibrated PLA profile.
The R8 insert bores open upward and remove the old nut-pocket roof bridges.
Strap/wire-anchor tunnels still require approximately 8.4 mm bridges, and the
switch opening has a 13.5 mm roof bridge. **PrusaSlicer 2.9.6 flagged "Floating
bridge anchors" on earlier bases** during the 0.20 mm/5-perimeter slice check.
Support-free printing of R8 is unverified: inspect those remaining spans layer
by layer, and test a cropped anchor section or paint removable local supports
with accessible removal paths. The insert coupon reproduces the boss depth and
bores, but does **not** test the strap or switch bridges.
The LED window is open to the rim in the base; its upper frame prints as part of
the lid. The rear LED guides rise from the floor, inboard of the solder zones.
The end wire slots are open to the top, so they introduce no roof bridges.
The 0.3 mm lid clearance is **per side**. Deburr openings that contact wires.
The countersink openings face the bed and taper inward as the lid prints.
The default lid has no markings. Optional `lid_markings=true` engraves the exterior;
that version triggered a long-bridge warning in PrusaSlicer and is not the
supplied print default.

## Hardware and assembly

- Four **M3 heat-set inserts, 4 mm long × 5 mm outside diameter**, and four
  **DIN 7991 M3 flat-head machine screws**. Use **8 mm overall length**, or reuse
  the existing **12 mm** screws after checking tip clearance. Countersunk screw
  length includes the head. With a flush head and the 3 mm lid, an 8 mm screw
  projects 5 mm into the boss and a 12 mm screw projects 9 mm; the blind relief
  ends at 10 mm. Smaller heads can seat below flush and move the tip deeper.
  Confirm full insert engagement and that the screw clamps the lid before it
  bottoms. Heat-set inserts squarely from above, **flush with the boss top**,
  with electronics and battery removed. Follow your insert/filament installation
  guidance, test on the coupon, and let the inserts cool before threading screws.
  Clear any raised plastic so the lid seats flat. No hex nuts are used in R8.
  Snug by hand; do not torque a metal fastener hard against PLA. Recheck after
  early rides.
- Ten **M2 × 5 mm screws suitable for plastic pilots**: four for the Feather,
  two for the IMU, four for the SD breakout. Nominal pilot is 1.7 mm, blind,
  with 4 mm standoffs for the Feather/IMU and 7 mm for SD.
  Test the coupon's 1.6/1.7/1.8 mm pilots with your actual screw; change
  `pcb_pilot_diameter` if needed. These are not pre-tapped M2 machine threads.
  Avoid oversized heads touching components/traces, particularly at the Feather's
  smaller rear holes. Confirm screw engagement without bottoming or splitting posts.
- An **8 mm-wide soft fabric strap**, with a closure that fits inside the shell,
  through the battery anchors; about 100 mm of strap allows trimming to fit.
  Place approximately 0.8 mm of nonconductive soft padding under the pouch and
  secure it loosely so it cannot slide or rattle. No zip tie cinched around the cell.
- Small cable ties for strain relief, electrical insulation at exposed joints,
  and a short secondary tether secured to a fixed point clear of wheels and truck
  movement. It should prevent the enclosure reaching a wheel if the primary mount fails.
- Deck mounting fasteners/adhesive as chosen above; their lengths depend on your deck.
- No extra LED mounting screws or adhesive are required for the nominal bare PCB:
  the channel constrains it and the main lid stops upward travel. Optionally add
  a **54 × 11 × 0.5 mm clear polycarbonate cover**, centered over the side window.
  Bond its ends and lower edge to the **base only**, using a compatible adhesive;
  keep it free of the removable lid's window header. This is a separately cut
  cover, not a printed PLA part or a supplied STL, and it does not make a seal.

1. Print the insert/pilot coupon, SD mounting sample and the two LED fit samples.
   Confirm insert dimensions, test heat-setting and screw engagement after cooling.
   Select the bore size before printing the full base, then install all four
   inserts in the empty base. Check the SD board rests flat on all four posts
   and each screw engages gently.
   Check the complete
   wired stick drops into the sample and the sample lid seats without force.
   Then print and inspect the full parts. Turn the full lid over to face its tabs
   into the cavity, lining up the wide LED header with the LED opening and the
   USB tab with the USB cutout. **Do not mirror the STL in the slicer.** Fit the
   empty base and lid, then repeat with the wired electronics before tightening.
2. With power disconnected, screw the Feather, IMU and SD PCBs to their posts. The Feather USB points
   toward the **x=0 short wall**. Its battery connector faces the battery bay.
   The IMU components face the lid, with the PCB extending from its screw row
   toward the SD breakout. Keep the physical orientation used for recordings;
   slide it 12.7 mm toward the LEDs to reach the new posts. Route the STEMMA cable in the free space
   between boards. Record the real IMU silkscreen axes in `--mounting`; enclosure
   X/Y coordinates do not establish the sensor's firmware axes.
   The SD board sits at the opposite end from USB, beside the battery: card socket
   faces inward toward the battery, solder/header row toward the **x=108 wall**.
   Use insulated, flexible stranded leads with a little slack at the joints.
   Tie the wire bundle to the anchor at **(85, 70)**, clear of the lid boss and
   card slot. The mount prevents the PCB moving; it cannot repair a cracked joint
   or prevent stiff solid wires from loading their solder joints.
3. Pad and strap the battery in its separate tray, leaving its wrapped end and
   lead unstressed. Route the lead through the tray notch toward the Feather.
   Keep loose wiring clear of the lid seam and screw bosses. Tall plug-in headers
   are not assumed by this layout.
4. Solder and insulate the LED leads before inserting the stick. Slide the bare
   PCB down the channel along the **y=0 long wall**, pixels facing **negative Y**
   (outward), with the pad row toward the channel floor. It rests 5.5 mm above
   the enclosure back. Drop the solder joints and wires down the **open-top slot
   at either end**, and route them through that slot into the case. Each slot
   crosses the old end wall and extends 5 mm beyond and 5 mm inside the nominal
   PCB end. It runs from y=1 to y=11 mm and from z=4 mm up to the rim. Keep the
   joints and exiting leads below **z=11.5 mm** so the lid's upper-corner stops
   pass above them. The fit fixture allows a **9 × 9 × 7 mm envelope per end**,
   with 0.5 mm clearance to slot walls; this is an assumption to check against
   your soldering, not a measured wire model. Tie the insulated cable bundle to the anchor
   near **(18.15, 8)**, with slack between anchor and solder joints. It must not
   obstruct the adjacent Feather, lid guides, or the LED's vertical insertion path.
5. Fit the lid. Its front header finishes the LED opening; a separate internal
   stop leaves 0.8 mm above the PCB and prevents it lifting out. The two corner
   locators limit lengthwise movement without blocking the lower wire slots. Confirm the
   board is retained without being clamped, and all eight LEDs remain unobstructed.
   The other tongue closes the USB slot. The USB
   opening is **16 × 10 mm**; verify your actual USB-C plug housing reaches the
   recessed connector without loading the PCB. Buttons and the battery plug are
   accessed by removing the lid. The adjacent **13.5 × 8.4 mm** opening accepts
   the measured power-switch body from outside the x=0 wall. Check retention in
   the 3 mm wall and clearance for the actual terminals and wiring before fitting
   the lid. This revision adds the mounting cutout; electrical wiring is separate.
6. Aim this long side of the enclosure toward the camera. Check actual recorded
   sync flashes from the intended camera position, with the deck in place and
   optional clear cover fitted. Recessed pixels have a narrower viewing angle
   than an exposed stick; rotate/reposition the enclosure if the deck hides them.
7. Check clearance with the trucks fully steered, deck loaded/flexed and wheels
   near wheelbite. Keep the housing and LED window away from grind/slide contact.
   This PLA shell is not a grind plate or a verified battery crash enclosure.
   Start with a stationary Wi-Fi/LED check, then low-speed riding and inspection
   before progressively harder trials. Remove it for slides that would strike it.

The ports, seam and porous print are **not waterproof**. The battery must remain
removable and free of crushing loads; stop using a damaged or swollen cell.
The default has no boost-converter or level-shifter mounting, matching the
project's direct-LiPo wiring. Rework the layout if that circuitry is added.

## Dimensions and assumptions

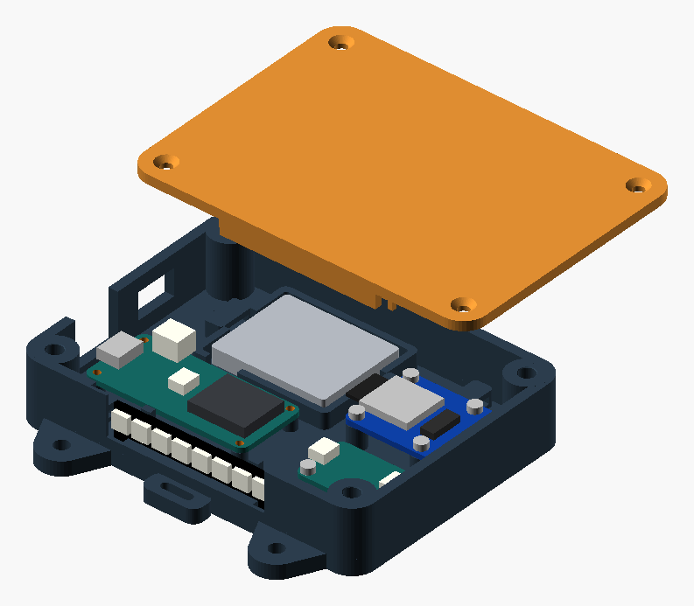
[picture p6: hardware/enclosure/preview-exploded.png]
Exploded enclosure and integrated LED channel


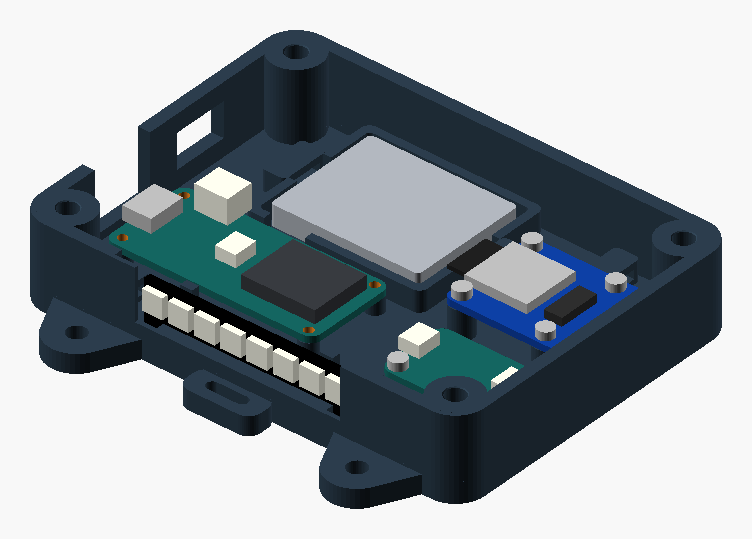
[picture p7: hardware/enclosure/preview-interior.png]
PCB and battery placement


The PCB outline and hole locations were read from the manufacturer's mechanical
files, not measured from the wiring illustration. Values below are relative to
each PCB's outline, in a top view using the Eagle coordinates.

| Item | Default / source |
| --- | --- |
| Feather ESP32-S3 8 MB / no PSRAM | 50.8 × 22.86 mm PCB; front holes (2.54, 2.54), (2.54, 20.32); rear holes (48.26, 1.8415), (48.26, 20.955), rear drill 2.2 mm. [Official PCB](https://github.com/adafruit/Adafruit-Feather-ESP32-S3-PCB/blob/main/Adafruit%20ESP32-S3%208MB%20No%20PSRAM.brd), [downloads](https://learn.adafruit.com/adafruit-esp32-s3-feather/downloads). |
| IMU | 25.4 × 17.78 mm PCB; two holes at (2.54, 15.24), (22.86, 15.24). Uses the [LSM6DSOX family PCB](https://github.com/adafruit/Adafruit-LSM6DSOX-PCB/blob/master/Adafruit_LSM6DSOX.brd) linked from the [combined IMU guide](https://learn.adafruit.com/lsm6dsox-and-ism330dhc-6-dof-imu/downloads), cross-checked against the bundled LSM6DSO32 Fritzing part. Confirm your revision. |
| microSD breakout | Adafruit 254: **31.75 × 25.4 mm PCB** from the [official Eagle file](https://github.com/adafruit/MicroSD-breakout-board/blob/master/microsd.brd); four 2.2 mm holes at (2.54, 2.54), (2.54, 22.86), (22.86, 2.54), (22.86, 22.86). The holes form a **20.32 × 20.32 mm square**, not equal corner insets. PCB underside is 10 mm above the case back; origin (71, 39). The [product page](https://www.adafruit.com/product/254) rounds the length differently (31.85 mm); verify the actual board. |
| LiPo | **Assumed 36 × 29 × 5 mm**, with 1.5 mm free space per side: a 39 × 32 mm bay. Reference [Adafruit 1578](https://www.adafruit.com/product/1578) is 36 × 29 × 4.75 mm. Your exact 500 mAh cell is unidentified; measure the complete wrap/protection end and lead bend. Capacity alone does not establish size. |
| RGB stick | 51.1 × 10.22 × approximately 3.2 mm from [Adafruit 1426](https://www.adafruit.com/product/1426). The channel assumes a 1.6 mm PCB, 0.3 mm clearance per end and per face; solder bumps/wires and variants need a fit check. Nominal pixel faces are recessed 1.9 mm behind the exterior wall. |

SD source checked 2026-09-26; other sources checked 2026-09-07. PCB, connector, battery and LED shapes in the colored
views are **simplified placement envelopes**, not detailed STEP models. They do
not prove connector, solder joint, header, fastener-head or cable-bend clearance.

Change the variables at the top of the SCAD file or in the Customizer. A larger
battery requires rechecking the SD posts, strap anchor and card path as well as
the tray; simply increasing the shell size does not relocate those features.
`sd_standoff` sets the SD post height. `show_sd_clearances=true` shows the assumed
card-removal and soldered-lead volumes. The lead envelope is 3 × 20.6 mm in plan,
from 1.5 mm below the PCB to 6 mm above its underside; tall plug-in headers are
not included. With the default battery there is 3 mm nominal clearance below
the card, before adding the battery strap. The card-access fixture includes
15 mm of withdrawal and 6 mm of space above its underside, with the lid removed.
Check that you can grip and remove the actual card without disturbing the cell.
`body_height` can be
increased for headers, but check the real assembly and USB position; the echo
prints the full-engagement length and blind-bottom limit for the lid screws. Moving the standoffs changes
USB height and needs port adjustment too. Changing layout dimensions requires
fresh geometry and physical checks. The supplied STLs contain **only defaults**.
`imu_rotation=180` is the R6 default: an in-plane turn relative to the old CAD
preview, with the screw row shifted to keep the PCB's modeled footprint fixed.
It is **not** an instruction to rotate the user's already-reversed physical IMU.
`imu_rotation=0` regenerates the earlier orientation and screw row. Neither
setting turns the component side toward the floor. Recheck clearance and mounting
metadata before using a different physical orientation.
`lid_countersink_diameter` sets the exterior opening and `lid_countersink_angle`
sets the included head angle. Depth is calculated from those values and the
3.4 mm shaft hole; an assertion keeps at least 1.2 mm of lid below the bevel.
`lid_insert_length` and `lid_insert_outer_diameter` describe the intended insert;
`lid_insert_bore_diameter` sets its printed fit. Bore depth is insert length plus
`lid_insert_depth_allowance` (1 mm default). The 0.2 mm lead-in is a 45° bevel;
`lid_screw_relief_depth` sets the total blind depth from the boss top. Insert OD
is a wall-thickness check, not the bore diameter. The coupon gives bore variants
at the selected diameter −0.2 / nominal / +0.2 mm, with matching depths and
full-height 12 mm bosses. It checks heat-setting and M2 pilots, not the lid's
countersunk head recess. Recheck the actual screw length if any depths change.
`power_switch_width` and `power_switch_height` set the exact switch opening;
`power_switch_y` positions its center along the USB wall. Its height is centered
between the floor and rim. These dimensions already include the requested fit
allowance; `fit_clearance` does not enlarge this opening.
`stick_clearance` controls the LED's end clearance at the lid locators.
`led_wire_end_space`, `led_wire_pad_space`, `led_wire_front`, and `led_wire_back`
control the two lead passages. `led_wire_top` specifies the assumed assembled
lead height for the clearance fixture. `show_led_wire_envelopes=true` displays
those assumed envelopes in red. The hidden
`led_pcb_thickness` assumption and the channel faces need adjustment if the real
PCB is thicker/thinner than 1.6 mm; increasing `stick_height` only changes the
illustrative component envelope. Do not add a back pad that makes the slide-in
channel a press fit. The nominal bare-PCB channel is 51.7 mm long × 2.2 mm deep.

## Rebuild and verification

From the repository root, export to a new directory:

```bash
python3 hardware/enclosure/build.py --output /tmp/judgy-enclosure
python3 hardware/enclosure/verify_fit.py --exports /tmp/judgy-enclosure
```

Use `--openscad /path/to/openscad` if necessary. On this Mac, the current version
is `/Applications/OpenSCAD-2021.01.app/Contents/MacOS/OpenSCAD`; the similarly named
`OpenSCAD.app` is the older 2015 release. To deliberately regenerate the checked-in
default outputs, use `--replace`. This only replaces this generator's named files.

In the GUI, select `base`, `lid`, `fit_coupon`, `led_fit_base`, `led_fit_lid` or `sd_fit_base` using `part`, then
**F6 → File → Export → Export as STL**. `assembly` and `exploded` are viewing modes.
`interior` shows the PCB and battery layout without the lid. `mount_ears=false`
selects the Velcro base.

The build script runs real OpenSCAD CGAL exports and checks each STL for paired
edges, consistent winding, a single connected surface, positive signed volume
and z=0 placement. Results are in [validation.json](exports/validation.json).
Rendered views were visually reviewed. Print quality, exact hardware fit, deck
clearance, RF performance and riding loads still require the physical checks above.

The current [fit-validation.json](exports/fit-validation.json) comes from checks against
the **exported STLs**, with a real 180-degree lid rotation. It checks lid/base,
electronics/base, electronics/lid, the LED sample pair, and the vertical insertion
path of the wired LED, including the stated end envelopes. SD checks include
the assumed screw heads and soldered leads, separation from other electronics,
card removal over the battery with the lid off, clear pilot holes and the SD
sample's post placement. A 0.02 mm lift excludes intentional
contact faces. The previous reflection-based fit check was inadequate and is
superseded. These checks still do not measure print shrinkage, warping, your solder
joints or real components; use the fit samples before another full print.
R6 adds the actual IMU orientation, assumed M2 screw heads (up to 4 mm diameter
and 2 mm high), clear IMU pilots, and separation from the wired LED insertion
path. A before/after check reproduced the reversed IMU's interference with the
R5 SD mount and cleared it after the 12.7 mm shift. These are simplified component
envelopes; confirm cable bends, connector plugs and screw access on the hardware.

R7 checks the switch through-opening and its surrounding wall in **both exported
base variants**, including clearance from the assembled lid. Independent fixtures
check the default 13.5 × 8.4 mm opening and its position within 0.01 mm. These
checks cover the aperture only; the switch bezel, clips, depth, terminals and
wiring still require a physical fit check.

The R3 PrusaSlicer 2.9.6 check generated toolpaths for the full base, full lid and both LED
test pieces with the settings above. The R3 lid and sample pair produced no slice
warnings. The base's bridge warning remains
as described under printing. The R4 countersunk lid also slices without warnings
in PrusaSlicer 2.9.6 at 0.20 mm layers, a 0.4 mm nozzle, 5 perimeters,
6 top/bottom layers and 40% gyroid infill. Trial G-code uses generic settings and is not
supplied as printer-ready output.

R5 also generated toolpaths in PrusaSlicer 2.9.6 with those settings. The SD fit
sample sliced without warnings. The full base still reports **Floating bridge
anchors**; inspect the captive-nut pockets and wire/strap anchors, including the
new SD wire anchor, and provide local support where needed. Its lid STL has the
same triangles as the R4 export.

R6's revised base also sliced with those settings. The same floating-bridge
warning remains; moving the IMU posts adds no new bridges. The lid and all fit
samples have identical oriented triangles to the R5 exports.

R7 retains the lid and fit-sample geometry. Its new 13.5 mm switch-opening bridge
has not been checked in PrusaSlicer; inspect that span before printing the base.

R8 checks both exported bases for all four stepped insert bores, their entry
bevels, solid surrounding bosses and blind bottoms, including filled former nut
channels. A separate 3 mm shaft fixture passes through each rotated lid hole
and down to the tip of an M3 × 12 mm screw seated 0.2 mm below flush. The coupon's
three bore sizes and surrounding material are also checked. These are nominal
CAD checks; they do not model plastic flow, insert threads or pull-out strength.
The lid and LED/SD samples retain their R7 geometry. R8 has not been slice-checked;
inspect the remaining strap/wire-anchor and switch bridges before printing.

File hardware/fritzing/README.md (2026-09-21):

# Editable skateboard wiring project

Open **[skate-judge-direct-lipo.fzz](skate-judge-direct-lipo.fzz)** in Fritzing.
It contains native components, electrical connections, movable wire bendpoints,
labels, and editable notes—not a flattened drawing. All six part definitions
and their artwork are bundled, including the four official Adafruit boards.
No separate part-library download is required to open the bundle.

Preview of the direct-LiPo wiring

## Open and edit

1. Install [Fritzing for macOS](https://fritzing.org/download/) if needed. The
   official prebuilt download requires a purchase; no purchase or application
   installation was performed as part of creating this project.
2. In Fritzing, use **File → Open** and select `skate-judge-direct-lipo.fzz`.
3. Select **Breadboard** view and zoom to fit. This is a direct-wired assembly;
   there is no physical breadboard in the drawing.
4. Move components, drag wire bendpoints, or edit the notes. The wires reference
   real part connectors, including the battery JST and STEMMA QT contacts.
5. Keep saving as **`.fzz`** so custom parts travel with the project. Use Save As
   for a new circuit variant before changing the power arrangement.

The `.fz` file is the initial uncompressed sketch for inspecting changes in Git.
The `.svg` and `.png` are generated previews, **not** the editable Fritzing source
and **not** exports from a running Fritzing application. After editing in Fritzing,
the saved `.fzz` is authoritative; these initial snapshots will not update themselves.

Only the breadboard wiring view is authored and reviewed. Schematic/PCB component
positions are provided, but those views are not routed or reviewed. This is not
a fabrication-ready PCB, a simulation, or a dimensional mounting template. The
battery graphic is a generic 1S 500 mAh illustration, not a model of your exact cell.

## Circuit represented

| Connection | Destination |
| --- | --- |
| 3.7 V / 500 mAh LiPo | Feather battery JST, correct polarity |
| Feather `BAT` | NeoPixel stick `5V` / `+` input; actual supply is battery voltage |
| Feather `GND` | NeoPixel stick `GND` |
| Feather pad **5**, GPIO5 | R1, **330 Ω**, then stick `DIN` |
| Stick `DOUT` | Unconnected |
| Feather STEMMA QT | IMU STEMMA QT: GND, switched 3.3 V, SDA/GPIO3, SCL/GPIO4 |
| Feather `3.3V` | Adafruit **254** `3V` |
| Feather `GND` | 254 `GND` |
| Feather `SCK` / GPIO36 | 254 `CLK` |
| Feather `MO` / MOSI / GPIO35 | 254 `DI` |
| Feather `MI` / MISO / GPIO37 | 254 `DO` |
| Feather **10** / GPIO10 | 254 `CS` |
| 254 `5V`, `CD` | Unconnected |

The four IMU wires represent **one STEMMA QT cable**. GPIO7 enables the Feather's
QT supply in firmware; it is not a fifth wire. The red QT wire is **not** the same
power net as red `BAT`. The 330 Ω resistor is the recommended data-input protection,
not an LED current-limiting resistor. Crossing lines are not connected unless they
meet at an electrical connector/junction.

The [Adafruit 254](https://www.adafruit.com/product/254) is the level-shifted
microSD breakout board+, with `DI`/`DO` labels. Its `3V` pin can accept a regulated
3.3 V supply, as [Adafruit support confirms](https://forums.adafruit.com/viewtopic.php?p=755866).
This uses the Feather's main 3.3 V rail, separate from the switched QT supply.
Keep SPI wires short. Insert a FAT32 card before boot and stop/save before removing
power or the card. See [SD recording and verification](../../docs/onboard-recording.md#sd-card-and-internal-flash)
for storage selection, firmware settings, and the required physical bench test.

This is the documented **direct-LiPo first test**, not the regulated 5 V alternative.
The stick's listed supply range is 4–7 V, so operation as a single LiPo discharges
below 4 V is not guaranteed. Test both fully charged and partly discharged before
relying on the sync flashes. Verify battery polarity and protect it from impacts.
See the [hardware reference](../../docs/recording.md#direct-lipo-wiring-for-the-first-test)
for the wiring caveats, manufacturer sources, and regulated-power alternative.

## Verification and reproducibility

The bundle was checked for valid XML, ZIP integrity, complete part/SVG references,
reciprocal wire connections, and the expected isolated electrical nets. In particular,
the checker rejects a bypassed/wrong data resistor, connections to LED DOUT,
Feather USB, SD 5V or CD, swapped SPI signals, and shorts between the twelve
expected nets. The updated preview was rendered with librsvg and visually reviewed.

**Native Fritzing open/save testing has not been performed** because the application
was not installed in this environment. Check that it opens without missing-part
warnings and that wires stay attached when moving a board before relying on it as
your working project. Physical hardware operation is also not established by a diagram.

From the repository root:

```bash
python3 hardware/fritzing/validate_project.py hardware/fritzing/skate-judge-direct-lipo.fzz
python3 -m unittest discover -s tests -p test_fritzing_project.py -v
```

`build_project.py` recreates the **initial layout** from the checked-in parts using
Python's standard library. It refuses to overwrite an existing project by default:

```bash
python3 hardware/fritzing/build_project.py --output /path/to/new-preview-directory
```

The optional `--preview` additionally needs PyQt6 and produces a PNG. The internal
`--replace-generated` option deliberately overwrites the initial outputs and will
lose any hand edits to them; do not use it on your working Fritzing file.

## Parts and attribution

- Feather ESP32-S3, LSM6DSO32, RGB NeoPixel Stick, and Adafruit 254 artwork/definitions:
  [Adafruit Fritzing Library](https://github.com/adafruit/Fritzing-Library), pinned
  at `7d905c3e982de3712c3033da4596cc71ea32de1c`. The Feather asset identifies the
  8 MB revision; the RGB stick asset is not the WWA or RGBW part.
- Standard resistor artwork/definition: Fritzing / Brendan Howell,
  [Fritzing parts](https://github.com/fritzing/fritzing-parts), pinned at
  `e64ffe973e92176b989ab390ab668638a85ee305`. R1's native resistance property is 330 Ω.
- Generic battery illustration and arrangement: skate-judge contributors.
- Upstream URLs and archive hashes: [sources/provenance.json](sources/provenance.json).

The diagram, bundled artwork, and generic battery part are distributed under
**Creative Commons Attribution–ShareAlike 3.0 Unported**. Attribution is also inside
the `.fzz`; see [the license](sources/CC-BY-SA-3.0.txt) and
[Fritzing's graphics notice](sources/Fritzing-LICENSE.txt). This notice does not
relicense the firmware or the rest of the repository.

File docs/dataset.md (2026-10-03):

# Accumulate a labeled dataset

The session directories are the source dataset. Keep each recording's
`samples.csv`, `metadata.json`, raw `.bin`, video, `video_sync.jsonl`, and
`labels.jsonl` together. Saving in the review UI already accumulates labels;
there is no need to download and combine the clip exports manually. Label
corrections append a revision with the same ID. Count the last revision per ID,
not lines in `labels.jsonl`.

## Collection loop

1. Record into a new session directory such as `sessions/a7s-005`.
2. Open its video with `uv run viz/trick_review.py sessions/a7s-005/<video>.MP4`.
   Match the LED flashes, review each attempt, save its trick and outcome, and
   label observed background ranges. Skipped proposals remain unlabeled.
3. Run `python3 capture/dataset.py status` from the repository root. It scans
   every `sessions/a7s-*` directory and reports unique saved labels, eligible
   attempts, background, unknown outcomes, exclusions, and trick/outcome counts.
4. Build a snapshot when you want to train or compare versions:

   ```bash
   python3 capture/dataset.py build --output datasets/a7s-v1
   ```

Continue labeling in the original sessions. Status always reads their current
saved state; exports are frozen. Build `datasets/a7s-v2` after adding data or
correcting labels. Existing snapshot directories cannot be overwritten, so a
model can refer to the exact dataset version it used. No training is implemented
by this command, and export is explicitly run rather than automatic on each save.

Use `--sessions /path/to/sessions --pattern 'pilot-*'` to select another collection.
The default deliberately omits bench recordings outside `a7s-*`. Python 3.10+
is sufficient; no scientific packages or cloud service are required.

To refresh all saved labels when the collection also contains unfinished or
failed unlabeled recordings, use:

```bash
python3 capture/dataset.py status --labeled-only
python3 capture/dataset.py build --labeled-only --output datasets/a7s-v2
```

Choose a new, unused version directory for each build. `--labeled-only` skips
directories with missing or empty `labels.jsonl`; the report records them in
`skipped_unlabeled_sessions`. Malformed label files and missing or unreadable
sensor data in labeled sessions still block the build. All eligibility rules
below remain in effect, so compare saved, eligible, and excluded counts after
every refresh. Excluded labels remain in the manifest but have no exported
sensor samples. Run `status` without the flag to inspect the entire collection.

## Export format and eligibility

| File | Contents |
| --- | --- |
| `manifest.jsonl` | One row per latest saved label, including excluded labels and their reasons; original label/provenance, session ID, rider, board, sample count, and eligibility flags |
| `samples.csv` | Original six-axis samples for eligible windows, joined to the manifest by `example_id`, with sensor and window-relative seconds |
| `report.json` | Counts, session issues, source paths, and SHA-256 hashes of metadata, labels, alignment, and sensor CSV |
| `README.txt` | Units, joins, and evaluation reminders |

`example_id` combines session name and label ID. Windows include samples at
`start_s <= t_s < end_s`; adjacent windows do not share an endpoint sample.
Acceleration is m/s² and angular velocity is rad/s. Samples retain their
recorded rate, axes, and variable window lengths; export does not resample,
normalize mounting orientation, extract features, or assign train/test splits.

Only video-reviewed labels with current measured alignment and available source
video qualify. Synthetic/unverified or unclosed recordings and onboard sessions
whose quality check is not usable are excluded by default; the explicit
sample-gap exception below can admit complete recordings with that sole issue.
Other exclusions include stale
video identity, out-of-coverage or overlapping labels, windows with fewer than
two samples, gaps over 30 ms (including boundary gaps), zero acceleration
samples, and channels within 1% of the configured LSM6DSO32 raw full scale.
Nonfinite channels or nonmonotonic timestamps make a session unreadable. These
are conservative integrity checks, not verification that a human label is right.
Clipping thresholds assume the project's ±32 g / ±2000 dps configuration.

Unknown outcomes remain in the manifest and, if eligible, in the sensor export;
they have `outcome_training: false`. For supervised outcome training, select
`outcome_training: true`, then join the samples. Background ranges remain a
separate class. Neither background nor unknown counts toward the attempt total.
Unreviewed time, skipped proposals, and audio suggestions never create examples.

A single flash match is accepted with a warning because drift is unmeasured;
match a second flash when possible. A missing trick name is also reported.
Fix stale labels in the review UI and save again. Session-level quality flags
require investigating the recording; the exporter does not clear them. In
particular, a flash-capacity stop should be reviewed before deciding whether
any recorded portion can be salvaged. Unreadable source files block building a
snapshot rather than silently dropping a session.

Keep and back up original session folders: the export contains labeled IMU
windows, not copies of videos, raw logs, or complete continuous recordings.
Both `sessions/` and `datasets/` are excluded from Git and are not uploaded.

### Accepting a session with small sample gaps

The onboard importer flags `sample_gaps_over_10ms` if any interval between
consecutive sensor samples exceeds 10 ms. By default this marks the entire
session unusable, even if most labeled windows are unaffected. The exporter
also checks each window independently, rejecting gaps over 30 ms, including
gaps crossing a window boundary.

After inspecting the recording, use a session-specific exception to accept
the importer gap flag while retaining the window checks:

```bash
python3 capture/dataset.py status --labeled-only --allow-sample-gaps a7s-018
python3 capture/dataset.py build --labeled-only --allow-sample-gaps a7s-018 \
  --output datasets/a7s-v3
```

Use an unused output directory on every refresh and repeat the option to retain
the exception in future snapshots. It applies only if the named session is
complete and its only onboard issue is `sample_gaps_over_10ms`. Other acquisition
or storage faults still exclude the session. All alignment, coverage, clipping,
and per-window gap checks remain active; no samples are interpolated or changed.
The source metadata stays intact, `report.json` records `allow_sample_gaps`, and
session and label warnings identify the exception. Repeat the option for another
reviewed session; unlisted sessions keep the original policy.

For `a7s-018`, ten intervals were approximately 10.1–10.5 ms, compared with a
typical 5.1 ms interval. The recording completed with no reported I/O errors or
FIFO overruns and no gaps over 30 ms. The exception includes its valid windows;
the landed backside 180 remains excluded for sensor clipping near full scale.

## Planning the first model

Treat **100 labeled attempts as a collection milestone**, not a required minimum
or proof that a model is ready. Start building the feature/training pipeline
earlier; use more varied data to evaluate whether it works. For a small pilot,
focus on one or two tricks and collect both makes and natural misses for each
across several sessions. Track trick × outcome counts, not just the grand total.
If every ollie is a make and every kickflip a bail, an outcome classifier may
learn the trick instead of whether it was landed.

Collect observed background such as pushing, rolling, carrying, and waiting.
Keep makes, bails, and falls separate in source labels even if an initial model
combines bail/fall as a miss. Do not stage falls to balance a class.

Hold out whole sessions; use rider groups when testing new-rider generalization.
Randomly splitting sensor samples or neighboring windows would put closely
related motion into both training and test data. See
[scikit-learn's grouped cross-validation guidance](https://scikit-learn.org/stable/modules/cross_validation.html#cross-validation-iterators-for-grouped-data).
Keep continuous held-out recordings to measure false triggers as well as
accuracy on preselected trick windows.

Once several labeled sessions contain the classes you want to predict, compare
a simple feature-based baseline at increasing dataset sizes. Use validation
performance and a [learning curve](https://scikit-learn.org/stable/modules/learning_curve.html)
to decide what more data helps. Board motion may identify a trick while leaving
rider outcome ambiguous; there is no promised dataset size that solves that.

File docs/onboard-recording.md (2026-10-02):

# Onboard motion recording

`flash-feather.sh` installs `firmware/imu_logger`, and `capture/onboard.py`
controls it. The older `firmware/imu_stream` / `capture/session.py record`
workflow remains available for live viewing and synthetic demos.

## Acquisition and sync

The LSM6DSO32 is configured for nominal 208 Hz acceleration and angular velocity, with ranges
±32 g and ±2000 degrees/second. Both streams and sensor timestamps enter its
hardware FIFO. An acquisition task drains tagged, uncompressed FIFO words into
a 32 KiB RAM queue; a separate task writes the binary log to SD or internal flash.
Every I²C read must return its requested bytes;
configuration registers are read back. The tag and six data bytes are read in
separate transactions, and tag parity/duplicate time-slot entries are checked.
Non-consuming tag reads have bounded retries; a failed payload read is retried
only if the FIFO head still matches, proving that word was not consumed.
`bus_retries` is displayed and retained separately from unrecovered read errors.
FIFO overflow, read failures, persistently
low rate, and excessive all-zero acceleration stop the log and report a fault.
The sensor configuration and FIFO registers follow the
[ST datasheet](https://www.st.com/resource/en/datasheet/lsm6dso32.pdf).

**Record video + sync** waits for MediaRecorder to start and for the first video
chunk to be saved on the laptop, then starts onboard logging and checks actual
accel/gyro rates (180–230 Hz). Only then does the three-second countdown begin.
Another countdown uses the same running video and sensor log. External cameras
require the explicit “already recording” checkbox.

Both LED edges are timestamped on the ESP32 and written into that same log.
Periodic bracketed clock reads map sensor FIFO timestamps onto the ESP32 clock.
Import fits those anchors, compares them with the chip's signed factory
`INTERNAL_FREQ_FINE` calibration, and rejects inconsistent clocks. The actual
rate can differ from nominal: the tested IMU has a factory trim of −38 and
measures about 196.5 Hz, with approximately 5.09 ms sample spacing. This agrees
with the calibration formula in [ST AN5473, section 6.4](https://www.st.com/resource/en/application_note/an5473-lsm6dso32-alwayson-3axis-accelerometer-and-3axis-gyroscope-stmicroelectronics.pdf).
Wi-Fi arrival times are never used as sample timestamps. The LED write and actual light output have
a small hardware delay; matching a video frame also has exposure/frame-rate
uncertainty. Match beginning and ending flashes in the review UI to estimate
video offset and drift. Automatic flash recognition is not implemented.

208 Hz gives roughly 4.8 ms sample spacing. It is a useful initial rate for
takeoff/landing boundaries, not a guarantee of capturing an impact's true peak.
Inspect clipping and timing in real skating data before selecting final detector
thresholds or increasing the rate.

The replacement Feather passed a 61.99-second bench capture on 2026-09-09:
12,184 matched accel/gyro samples at 196.53 Hz, no retries/read errors/overruns,
no missing or duplicate slots, and three recorded sync pulses. A 20-second
host-client disconnect preserved 3,982 additional samples. A second capture on
the same boot also passed. The raw downloads and CSV imports were validated;
physical LED visibility and real skating impacts still require video review.

## SD card and internal flash

The logger now prefers an **Adafruit 254 microSD breakout board+** with a mounted
card. The [editable Fritzing design](../hardware/fritzing/skate-judge-direct-lipo.fzz)
includes these connections:

| Feather ESP32-S3 | Adafruit 254 |
| --- | --- |
| `3.3V` | `3V` |
| `GND` | `GND` |
| `SCK` / GPIO36 | `CLK` |
| `MO` / GPIO35 | `DI` |
| `MI` / GPIO37 | `DO` |
| `10` / GPIO10 | `CS` |

Leave `5V` and `CD` unconnected. The `3V` pin accepts a regulated 3.3 V supply
([Adafruit confirmation](https://forums.adafruit.com/viewtopic.php?p=755866));
do not connect it to BAT. The main Feather 3.3 V rail powers the card, while the
IMU remains on switched STEMMA QT power. Use short SPI wires.

Use a **FAT32** card, such as the previously selected 32 GB SanDisk High Endurance.
Insert it with power off, then boot. The firmware mounts without formatting and
creates `/skate-judge/`; recordings are `/skate-judge/<32-character-id>.bin`.
No card, a mount failure, or an unusable recording directory selects internal
flash instead. Status and the recorder show `storage: "sd"` or `"flash"`,
`sd_ready`, `flash_ready`, free bytes, and a fallback warning. Selection remains
fixed until reboot. Temporary SD write/flush failures trigger on-board recovery
while acquisition continues. It does not start a second file on another medium. There is no
hot-swap support. A read-only/full card that mounts can still fail at recording
start; correct that issue or power down and remove it to use flash.

The recorder displays a prominent **SD card not in use** warning above the
storage estimate when the board reports internal flash with SD unavailable.
It appears before recording and stays visible during capture, so check the much
smaller available recording time before starting a batch. Save any active
recording before powering off to check the card and its connection. Restart the
laptop recorder to load this UI update; no firmware upload is needed.

The Feather build enables SD by default. Upload with `./flash-feather.sh` when
ready. `SKATE_SD=0 ./flash-feather.sh` disables it. `SD_CS_PIN`, `SD_SCK_PIN`,
`SD_MOSI_PIN`, `SD_MISO_PIN`, and `SD_SPI_HZ` can override the defaults
10/36/35/37/4000000. Keep the wiring and settings consistent.

SPI runs at **4 MHz**, a raw ceiling of 500 kB/s. The log requires approximately
4.5 KiB/s (roughly 16 MiB/hour). Protocol/filesystem overhead and card write
pauses reduce actual throughput; the clock rate is not a card benchmark.
The 32 KiB queue provides roughly seven seconds of buffering at that log rate.
Bytes remain in that queue until a successful flush and fsync, so unconfirmed
writes can be replayed after a temporary SD error.
Disk writes, flushes and free-space queries run on the writer task while the
acquisition task continues draining the sensor FIFO. Buffer exhaustion is an
explicit `storage_buffer_full` fault. Files stop before FAT32's 4 GiB file limit;
they are never automatically rotated or overwritten. Use separate manageable
batches: laptop import currently holds decoded samples in memory.

The Adafruit 254 and installed 32 GB card passed a USB-connected bench test on
**2026-09-21**, using the 4 MHz SPI configuration above. A 300.25-second recording
produced 58,853 samples at 196.01 Hz, with zero read errors, retries, FIFO overruns,
or detected sample gaps (maximum spacing 5.102 ms). All three paired sync markers,
download CRC32, packet CRCs, and import quality checks passed. The raw file was
1,394,746 bytes. Peak queue occupancy was 343 of 32,768 bytes; maximum measured
write and flush times were 0.390 ms and 21.564 ms. A second 10.45-second recording
on the same boot also passed, including three sync markers. Verified test logs
were removed from the board; SD free space returned to 31,902,334,976 bytes.
These results establish SD operation for this USB bench setup; battery-only
operation and skating impacts still need testing. Local raw files, status samples,
imports, and the full report are under `.build/board-check-20260921/`.

Repeat the bench check after changing the card, wiring, or firmware:

1. Run `uv run --offline capture/onboard.py --board serial:auto status` and
   confirm `storage` is `sd` and free space matches the card, including above 4 GiB.
2. Record a five-minute bench batch, exercise several sync flashes, then stop,
   download, and import. Check `onboard_quality.usable`, normal measured rates,
   and zero read errors/FIFO overruns. Repeat on battery power.
3. Inspect `storage_queue_peak_bytes` against `storage_buffer_bytes` (32768),
   and `storage_max_write_us` / `storage_max_flush_us` in status. The footer
   includes timing through the pre-footer flush; status includes the final flush.
   These measured pauses and queue headroom establish whether the actual card
   and wiring keep up.
4. Power off, remove the card, reboot and confirm the explicit flash fallback.
   Existing flash recordings remain listed/downloadable with the card installed.

## Internal flash capacity

The Feather preset keeps `default_8MB` and its existing **1.5 MiB data partition**.
The rest of the 8 MB is not available to this logger. No PSRAM is required.
LittleFS is never automatically formatted after a mount error. Initialize an
unused partition once:

```bash
uv run capture/onboard.py --board serial:auto initialize
```

This refuses to erase nonblank, unrecognized storage. Preserve it before changing
partition layouts or attempting recovery. Normal firmware uploads with this
unchanged partition layout leave recorded files in place.

Tagged accel/gyro/timestamp words consume about 4.4 KiB/s before packet and
filesystem overhead. Capacity is a few minutes when empty. **Start with one-minute
batches**, watch free space, download, verify, and explicitly reclaim space.
The logger stops before exhausting the partition. It never rotates files or
overwrites an old recording. SD removes this small internal-storage limit without
changing the partition layout or moving existing flash logs.

The saved `a7s-001` through `a7s-004` raw logs use approximately **4.4–4.5 kB/s**.
An empty 1.5 MiB partition has roughly **5½ minutes** of recording capacity after
reserved space and filesystem overhead; this is storage capacity, not battery
runtime. `a7s-004` itself recorded 93.66 seconds before `flash_capacity_reached`.
Previous recordings occupy space until explicitly deleted, even after downloading.

FIFO packets are queued at least every 50 ms while healthy, and the writer schedules
flush/fsync every 250 ms. These are scheduled intervals, not a hard power-loss
guarantee: abrupt loss can discard pending FIFO/RAM/filesystem data. Recovery
retains valid whole packets and marks a missing footer or truncated tail
incomplete. CRC and sequence failures are rejected; no missing samples are
invented. Prefer **Stop & save** before removing power.

## Diagnose an SD write or flush fault

`storage_flush_failed` means `fflush` or `fsync` returned an error. The older
firmware stopped on the first failure. It does not establish whether the cause was the
card, wiring, supply, or software. Repair any visibly loose connection first,
with power off, and secure the wiring against movement. A stable common ground
between the Feather and SD breakout is required.

Current firmware reports `storage_diagnostics_version: 2`, the configured
`sd_spi_hz`, and `storage_diagnostics` in `/status`. The diagnostics retain the
first failing operation, its `errno`, the device timestamp and operation duration,
bytes accepted by stdio, and the bytes/time of the last successful flush+fsync.
An errno of zero means that the failing call did not supply an error code; it
does not mean success. Accepted bytes are not a durability guarantee. A successful
closing footer includes the pre-footer diagnostics; final status includes close
errors too. The first error stays visible even after successful recovery;
`synced_bytes` and `last_sync_us` advance again only when recovery succeeds.

For an SD write or flush error, the writer now retains every byte since the last
successful fsync in RAM. It closes the failed file, remounts without formatting,
and reopens the same file without creating or truncating it. Before replay it
checks the file size and the retained boundary of the previously synced data.
It replays the pending bytes at the last synced offset, performs flush+fsync,
and reads back the replayed bytes before releasing the RAM. This avoids duplicate
packets and avoids trusting a simple fsync retry on a failed FatFs file object.
FatFs documents that an I/O error can abort an open file object in its
[return-code reference](https://elm-chan.org/fsw/ff/doc/rc.html).

Sampling and LED sync continue on the acquisition task during recovery, without
any laptop connection. Recovery attempts have a five-second budget; individual
driver calls can take longer. Buffer exhaustion, an unrecoverable changed file,
or failure to recover stops the recording with an explicit fault. This cannot
repair damaged FAT metadata, survive a board power loss, or record indefinitely
with an unavailable card. Internal flash retains its existing fail-fast behavior.

Status reports `storage_recovering`, `storage_recoveries`,
`storage_recovery_attempts`, and `storage_pending_bytes`. The recorder shows
**Buffering** during recovery and retains the recovery count after it succeeds.
The footer and downloaded metadata retain the count too. A recovered recording
must still pass the normal packet CRC, sequence, sample-count, and timing checks;
a recovery count alone does not make it unusable. Restart the laptop recorder
to load the updated display.

On 2026-09-25 the GPIO6 / 4 MHz build passed a hardware recovery check with two
deliberately injected fsync errors. Both occurred during a 15-second period with
the USB control client closed; the board recovered twice and collected 2,954
additional samples without host commands. The verified 46.7-second raw log
contained 9,175 matched samples at 196.46 Hz, three paired sync markers, no
incomplete slots, and maximum sample spacing of 5.091 ms. The injected errors
were returned after real fsync calls succeeded, so this checks remount/replay on
the actual card without deliberately corrupting it. Native tests separately
cover partial writes, a vanished unconfirmed tail, failed flushes, failed
remounts/read-back, changed files, and permanent outages. This bench check does
not reproduce a loose connection or a battery supply interruption. Test firmware
was replaced with the production build; saved artifacts are under
`.build/recovery-check-20260925/`.

The restored production build then passed a 361.5-second USB-powered recording:
71,014 matched samples at 196.46 Hz, no storage interruptions, read errors,
FIFO overruns or incomplete slots, three paired sync markers, and maximum sample
spacing of 5.091 ms. The queue peaked at 1,569 of 32,768 bytes and the longest
flush took 20.524 ms. Download CRC, packet checks and the closing footer passed.
Only the locally verified bench recordings were deleted; the original board
recording list and sizes were unchanged across both firmware uploads and tests.

While connected, the laptop recorder saves `board_status.jsonl` approximately
once per second and immediately on phase/error/recovery changes. It also saves an observed
fault to `board_fault.json`, before Stop & save. The stop status is retained in
`metadata.json` before download begins. Import after a reboot also picks up a
saved fault when its recording ID and boot ID match the raw file. These host files
cannot capture a failure that occurs while the laptop is disconnected.

Build the diagnostic firmware with `./flash-feather.sh --compile-only`; upload
with `./flash-feather.sh` once the board is idle and recordings are backed up.
Then use a fresh session for each comparison:

1. Keep the current 4 MHz SD clock and repaired wiring. Record at least ten
   minutes on USB power, stop, download, and check `onboard_quality.usable`.
2. Repeat on battery power with the laptop connected by Wi-Fi, so USB does not
   change the power conditions. First keep the board still, then test ordinary
   movement with secured wiring. Save the status journal for each run.
3. If it still fails, compare a 1 MHz build (`SD_SPI_HZ=1000000 ./flash-feather.sh`)
   under the same conditions. Espressif recommends lowering the clock as a
   diagnostic for SD communication problems in its
   [SD SPI example](https://github.com/espressif/esp-idf/blob/master/examples/storage/sd_card/sdspi/README.md).
4. Compare another known-good FAT32 card only after preserving the original.
   Keep the power, clock and wiring unchanged for that comparison.

A pass on USB alone does not validate battery-powered skating. If failures
follow movement or power source, inspect the ground/supply joints and SPI wiring
and measure the SD board's supply during writes. If a particular card fails
across stable configurations, investigate that card/filesystem. Keep the raw log
and fault diagnostics before making further changes.

## Record and download

To check the physical LEDs without starting a recording, install the current
logger with `./flash-feather.sh`, then run while the board is idle:

```bash
uv run --offline capture/onboard.py --board serial:auto test-led
```

This sends three one-second white pulses and leaves the stick off. Omit
`--board serial:auto` to use Wi-Fi. Status reports the installed `led_pin`,
`led_count`, `led_format`, and `led_brightness`; the Feather preset uses GPIO5,
eight pixels, GRB, and 255/255. Completion confirms LED commands, not visible
light. With the stick powered from `BAT`, leave the LiPo connected. GPIO5 must
connect to the stick's `DIN` input. The test does not write recording files or
sync markers, and it is blocked during recording.
It also samples battery voltage before and during a pulse using the Feather's
MAX17048 (unavailable on older gauge revisions), and checks that the GPIO's RMT
transmitter is attached and idle after sending. These diagnostics cannot verify
voltage at the stick's solder pads or detect visible light; `-1` means unavailable
or not yet tested. These before/during-pulse readings are separate from the live
battery display below.

### Live battery level

The recorder shows **Board battery** beside storage capacity, with estimated
charge percentage and voltage. The logger polls the Feather's MAX17048 every
five seconds while idle or recording. It reads the gauge's state-of-charge
register, rather than converting voltage to percentage. A compatible, connected
single-cell LiPo is required. The estimate does not measure current draw or
predict recording time, and it does not identify whether USB is charging the cell.
The gauge model and conversions follow the
[MAX17048 datasheet](https://www.analog.com/media/en/technical-documentation/data-sheets/MAX17048-MAX17049.pdf).

The panel warns at 20% and 10%; it does not automatically stop recording.
Disconnected, failed, or stale readings clear the displayed percentage. Older
firmware shows an update message; older Feather gauge revisions are unavailable.
Gauge reads share the acquisition task's I²C bus, have a short timeout, and are
deferred during sync pulses. A gauge read failure does not count as an IMU error.

Read the latest cached sample without flashing the LEDs:

```bash
uv run --offline capture/onboard.py status                     # Wi-Fi
uv run --offline capture/onboard.py --board serial:auto status # USB
```

Look for `battery_available`, `battery_percent`, `battery_mv`, and
`battery_age_ms`. An unavailable reading uses JSON `null` for percentage and
voltage. The sample is valid for at most 15 seconds. Restart the laptop recorder
after updating it to load the new panel. For the confirmed stick wiring on
GPIO6, upload using `SYNC_LED_PIN=6 ./flash-feather.sh`.

The GPIO6 build passed a USB-powered bench check on 2026-09-25: 6,605 samples
at 196.47 Hz, six battery refreshes during capture, and three paired sync pulses.
There were no read errors, retries, FIFO overruns, or sample gaps beyond the
normal 5.09 ms spacing. The gauge reported about 82% at 4.16 V. This validates
monitoring alongside acquisition, not battery-only runtime or percentage accuracy.
The verified bench log and report are in `.build/battery-check-20260925/`.

### Start recording

Join the Feather's `SkateJudge-XXXX` network, password `skate-judge`, then:

```bash
uv run --offline capture/onboard.py record --output sessions/pilot-001
```

Open the printed localhost URL, optionally enable microphone audio, and use
**Record video + sync**. Wi-Fi carries low-rate controls/status only during
capture. The page displays measured accel/gyro rates, errors, and free space.
The board continues logging if Wi-Fi disconnects, the browser closes, or the
laptop process exits. Reconnect to request the ending sync and download.
Keep the webcam recording running through a board connection outage.

The **Recording time left** panel shows an approximate storage budget alongside
SD/internal flash and free space. Before recording, it shows capacity for the next
log using a conservative 5,000 bytes/second estimate (or the last completed log's
measured rate). After five seconds of healthy recording, it uses logged bytes
divided by elapsed device time. It subtracts the 32 KiB firmware reserve and,
while recording, the full async buffer size to allow for pending writes. SD
estimates also respect the 4 GiB per-file stopping limit. Filesystem allocation
and variations in write rate mean this is an estimate, not an exact countdown.

The panel warns at one minute and becomes more urgent at 30 seconds. It clears
the estimate on a board/recorder disconnect, fault, or start/stop transition.
An idle board below the firmware's minimum starting free space shows that it
cannot start a new log. Battery runtime and space for laptop video are separate.
This UI also works with older onboard flash firmware; no reflash is needed just
to display the estimate. Restart the laptop recorder to load the updated UI.

After the final flash, **Stop & save video + board data** saves video, closes
the board log, downloads and verifies its byte count/CRC32 and packet CRCs, then
imports `samples.csv`, `events.jsonl`, and `metadata.json`. Retain the downloaded
`onboard-<id>.bin` as the original. `onboard_quality` records measured rate,
clock-fit error, gaps, zeros, incomplete FIFO slots, and firmware faults.
Host-arrival timestamps are blank because samples were recorded onboard.

If the sensor fails its ID/configuration check, recording is blocked. Check the
STEMMA QT cable and power, then run `check-sensor` while idle (with
`--board serial:auto` before it when using USB). This cycles the sensor's power
and rechecks its registers without deleting logs. A physical sampling-rate
check is still required after it reports ready.

Wait for both saved messages before `quit`. Start a new recorder command for
each batch. The stop/download button becomes available again if recovery needs
a retry. Downloading never automatically deletes the board's copy.

## Recovery and explicit deletion

Use `list` while idle to find IDs on both mounted media, including their `storage`
field. Add `--storage sd` or `--storage flash` to `list`, `download`, or `delete`
to select a medium explicitly (required if an ID exists on both).
If a capture is still running, `status` shows
its ID; stop it first. These example IDs and paths must be replaced with yours:

```bash
uv run --offline capture/onboard.py status
uv run --offline capture/onboard.py stop <id>
uv run --offline capture/onboard.py list
uv run --offline capture/onboard.py download <id> --output sessions/recovered-001
```

Use the original session folder to add sensor data beside an already saved
video, provided it has no existing `samples.csv`/`events.jsonl`. Existing imports
are not overwritten. An interrupted transfer keeps `.bin.part`; rerun the same
download to resume. A corrupt partial is preserved for investigation; use a new
output directory for a fresh download. After power loss, add `--allow-incomplete`
to import intact packets with explicit quality warnings.

You can also copy a stopped recording from the SD card into a session directory
and run `uv run --offline capture/onboard.py import <copied-file.bin> --output <session>`.
Imports record `onboard_storage` and use transport `onboard_sd`; older logs retain
`onboard_flash`. Both receive the same dataset quality checks and labeling flow.
Final close errors reported by the board are also preserved by **Stop & save**;
a raw-card import cannot recover an error reported only after the last packet.

USB supports the same protocol without joining Wi-Fi. Put the board argument
before the command, and close other serial clients first:

```bash
uv run --offline capture/onboard.py --board serial:auto status
uv run --offline capture/onboard.py --board serial:auto download <id> --output sessions/recovered-usb
```

After checking the local original and video, reclaim one recording's space:

```bash
uv run --offline capture/onboard.py delete <id> --downloaded sessions/pilot-001/onboard-<id>.bin
```

The single-run `delete` command requires a local raw file with the matching ID
and CRC32. To discard all board recordings without downloading them, stop any
recording, quit other USB clients, and run:

```bash
uv run --offline capture/onboard.py --board serial:auto wipe --yes
```

`wipe --yes` permanently deletes recordings on both mounted SD and internal
flash. Add `--storage sd` or `--storage flash` to limit its scope. It keeps laptop
sessions, unrelated SD files, firmware, and settings. Over Wi-Fi, omit
`--board serial:auto`. The command refuses to run during recording, reports
confirmed deletions, and checks that no recordings remain on the selected
storage. After an interruption, rerun it to finish. It works with the installed
logger and does not format storage or require a firmware update.

A board reset starts a new clock/boot ID;
the laptop refuses to combine that boot with an existing capture.

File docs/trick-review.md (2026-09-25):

# Audio and video trick review

Open a closed recording with audio:

```bash
brew install ffmpeg  # one-time, if ffmpeg/ffprobe are not installed
uv run viz/trick_review.py sessions/20260909-124749-8caf7e/webcam-670cc5c86ff8460883e75d5b6a4557f4.webm
```

Open **http://127.0.0.1:8766** on the same computer. The command prints the
address; use `--port 0` to choose a free port. Plain `python3` also works if
NumPy and SciPy are already installed. No cloud service or frontend build is
needed. Ctrl+C stops the server; saved edits remain on disk.

## Label a session quickly

After matching the LED flashes, use the same page to label every attempt. For
example, open the A7S clip with:

```bash
uv run viz/trick_review.py sessions/a7s-001/C0642.MP4
```

1. Select a suggestion and choose **Play attempt** to watch it with approach and
   roll-away. Slow playback and looping help when an outcome is unclear.
2. Check the **Range start / finish** fields. New windows include up to one
   second before the proposed pop and two seconds after contact, clipped to
   sensor coverage and neighboring saved labels. Use **I/O** to mark these
   boundaries at the playhead, or edit the times. Include enough roll-away to
   judge the outcome. The blue outline
   shows the full window; the green/orange markers are the pop/contact pair.
   Saved ranges appear in both the audio and sensor plots and in the overview.
3. Enter the trick name, then choose an outcome and **Save label**, or use a
   shortcut below. The last saved trick name carries forward for repeated
   attempts. Each new suggestion requires an explicit outcome.
4. For a false positive, choose **Not a trick** after watching the whole range.
   This immediately saves its window as `background` with an empty trick name.
   You do not need a separate background label for every onset. **Skip suggestion**
   leaves a proposal unlabeled; use it for duplicates or proposals you cannot
   judge. Existing rejections are not automatically converted to background.
5. **Advance after saving** is on by default. **Show only remaining** hides
   completed decisions; uncheck it to revise them. Revisions keep the same label
   ID. Only automatically proposed padding is trimmed; explicit edits are preserved.
   If the action itself or an edited range overlaps a saved label, the editor
   shows its name and times before saving. **Open overlapping saved label** lets
   you revise that label. Skip a duplicate suggestion; for separate attempts,
   adjust their ranges so each includes its own outcome without overlapping.
6. Scan the rest of the video for missed attempts, then use **+ Missed attempt**
   at the playhead and refine its window. Use **+ Background range at playhead**
   for pushing, rolling, carrying, waiting, or other observed background (see below).
   Unreviewed time and untouched suggestions never become background automatically.

## Label background by range

Label the real attempts first, then review stretches between them. Onsets are
places to look, not a checklist to complete.

1. Seek to the start of a stretch with no trick attempt and choose
   **+ Background range at playhead**. This creates an unsaved range starting
   there, initially up to three seconds long, ending before the next saved label
   or the end of sensor coverage.
2. Use **Play / pause** to watch the stretch. Pause at its end and press **O**
   (or **Finish at playhead**). **I** adjusts its start. The range can cover many
   onsets; pop/contact markers do not apply to background and are hidden.
3. Choose **Save label**. One background label covers the entire range.
   Untouched suggestions fully contained in it leave the queue, including after
   changing detection settings or reopening the page. Unsaved drafts remain for
   you to resolve. Partially overlapping suggestions remain visible with overlap
   guidance. Saving is blocked if the range overlaps an existing label.

Do not include a trick attempt in a background range, even if it was a bail.
Leave anything you have not watched unlabeled. Skipping suggestions does not
create background labels.

## Shortcuts and saved labels

| Shortcut | Action |
| --- | --- |
| Space | Play the selected range / pause |
| 1 / 2 / 3 / 4 | Save make / bail / fall / unknown |
| 0 | Save not a trick (`background`) |
| S | Save the chosen outcome |
| X | Skip without a training label |
| I / O | Set range start / finish at the playhead |
| N / P | Next / previous interval |
| Left / right | Previous / next recorded frame |

Shortcuts apply outside text fields, dropdowns, and the native video controls.
Space on a focused button activates that button. Frame stepping uses the review
video's decoded presentation timestamps, including variable frame intervals.
For the A7S 120 fps recording, the measured rate is 119.88 fps (120000/1001),
so adjacent frames are about 8.342 ms apart. The player displays the measured
rate and indexed frame count. Slow playback leaves label/sync timestamps in
original-speed seconds; it does not stretch the alignment.

The first launch indexes the review video's frames and caches `frames.json`.
This does not re-encode the clip or replace saved flash matches and labels.
Subsequent launches reuse the index unless the review media changes.

After updating the review tool, **restart the Python server**, then reload the
browser. Refreshing alone can load new page assets from an older running
server. The page detects incompatible responses and shows restart instructions.

**Make** means the rider lands and maintains control through the roll-away.
**Bail** means they step or jump clear without falling; **fall** means they
visibly fall to the ground. Use **unknown** when the outcome is unjudgeable.

Saving writes directly to the session's `labels.jsonl`, using the measured LED
alignment to map the attempt window onto `samples.csv` time. Reopening the page
restores saved labels and skips. **Download saved labels** exports the latest
revision of each label for this clip as JSONL, including background, original
video timestamps, mapped sensor timestamps, and review provenance. Unsaved
edits, skips, and unreviewed proposals are excluded. Use these intervals with
`samples.csv` to build training examples; this tool does not train a model.
To accumulate labels across clips and sessions, run
`python3 capture/dataset.py status`, then use the
[dataset export command](dataset.md) to create a versioned snapshot.

If alignment changes, affected labels are flagged for review. Save them again
after checking their windows; downloading labels is blocked until those flags
are resolved. Manual offset/scale changes are exploratory and cannot be used
for saving labels. A stale tab cannot overwrite another tab's or CLI's labels.

## Find and refine pop/contact boundaries

Expand **Onset detection settings** to tune the threshold and permitted gap
(default 0.18–0.90 seconds). Expand **Refine pop/contact markers** to edit those
boundaries, or drag their green/orange markers on the plot. They locate the
action separately from the full attempt window used for training labels.
Threshold changes preserve saved decisions and unsaved drafts in the open tab.
Proposals fully inside a saved, current label window are omitted as duplicate
work. A lower threshold can reveal missed attempts elsewhere.

Audio proposals require human review: speech, footsteps, truck rattle, and
handling the board can all trigger onsets. Some tricks have multiple contacts
or no clear audio pair. Gap settings are search parameters, not universal airtime
limits. **Export review JSON** includes the current suggestions, skips, labels,
and explicit draft status for diagnostics; use **Download saved labels** for
confirmed labels. Save each edited interval before closing the tab.

## Match the LED to the sensor clock

The **Accelerometer + gyroscope** plots are visible beneath the audio timeline
by default, with a sample count, start/finish markers, and the same time window.
Click the motion plot to seek. **LED sync & sensors** beneath the video jumps
to the plots and the expanded **Match LED flashes · align video and sensors** controls. Then
pause at the first frame where a known
LED flash lights up, select its recorded sync ID, and click **Match flash to
current frame**. Match another flash near the end to estimate drift. The app
stores correspondences in the existing session `video_sync.jsonl` and uses the
same alignment validation as `capture/session.py align`. Re-matching an ID
updates its correspondence with an appended revision. Inconsistent fits are
rejected before writing. A single point assumes no drift. The terminal asks for
a second flash only when one distinct flash is matched; with two or more it
reports the active drift correction. Re-matching a flash updates its existing
point rather than counting it as an additional flash.

If sensor data is missing, this section stays visible and identifies the missing
`samples.csv` or `events.jsonl`. Download or import the onboard recording into
the same session folder (see [onboard recovery](onboard-recording.md#record-and-download)),
then restart the review server and reload the page. Flash matching requires recorded
LED events and a closed/imported session. Recovered recordings retain acquisition
and storage warnings, including an incomplete recording after a failed stop.

The motion plots show raw acceleration and angular-speed magnitudes.
When no measured alignment exists, the suggested offset comes only from file
creation times and is explicitly **unaligned / exploratory**. Manually adjusting
offset/scale also gives an exploratory overlay. Sync matches must refer to
flashes actually visible in the selected clip; flashes from another clip cannot
establish this clip's alignment by themselves.

The viewer leaves gaps over 30 ms unconnected and reports sensor-quality issues.
LED sync aligns clocks; it cannot recover samples lost or corrupted at acquisition.
For the September 9 session, the data averages about 8 Hz instead of the intended
100 Hz, and about 55% of samples have all-zero acceleration. There are no missing
sequence numbers. That is a reason to investigate acquisition before using this
IMU stream as ground truth for audio/video timing.

## Method and timing

FFmpeg makes a seekable stream-copy review file, adding duration and an index
to browser WebM recordings. The original file is preserved. Both tracks receive
the same timestamp shift. Mono audio is decoded at 16 kHz; leading silence and
timestamp gaps are retained. The relationship is recorded explicitly:

```text
original_media_pts = review_video_seconds + source_pts_origin_s
session_seconds = scale * original_media_pts + offset
```

The audio features use centered 32 ms FFT windows with 10 ms steps. Positive
changes in log spectral magnitude between 180 Hz and 7.5 kHz, above a one-second
local median, emphasize transients. Strength is scaled to the clip's 99.5th
percentile. This is a spectral-flux baseline, following the general approach
described in [librosa's onset-strength documentation](https://librosa.org/doc-playground/latest/_modules/librosa/onset.html).
Timestamp padding uses [FFmpeg's audio resampler](https://www.ffmpeg.org/ffmpeg-resampler.html).

Pairing ranks two sufficiently strong onsets within the gap bounds, favoring
lower activity between them, then selects non-overlapping pairs. The score is
relative strength, **not a confidence probability**. The initial settings produce
21 suggestions on the specified clip; they have not been validated as 21 tricks.
Sound travel, microphone processing, and windowing limit boundary precision.

## Files and checks

Derived files live in `sessions/<session>/review/<video-stem>/`:

| File | Contents |
| --- | --- |
| `media.webm` or `media.mp4` | Seekable review copy |
| `frames.json` | Cached video frame timestamps, frame rate, and review-media identity |
| `analysis.json` | Cached waveform, onsets, timing, algorithm version, source identity |
| `review.json` | Skipped proposals, legacy boundary reviews, settings, revision |

The original recording and acquisition files remain unchanged. Flash matches
append to `video_sync.jsonl`. Human outcome/background labels and their revisions
append to the session's `labels.jsonl`; they retain both the full attempt window
and pop/contact markers. The latest row per label ID is authoritative. Legacy
boundary-only reviews remain separate until an outcome is explicitly saved.
The API checks review revisions, label-file revisions, and measured alignment
to prevent stale saves; local file locks serialize writers. `--rebuild` recreates derived media/audio
without deleting reviews. `--prepare-only` prepares files without starting a server.

```bash
python3 -m unittest discover -s tests -v
node --test tests/test_trick_review.mjs tests/test_webcam.mjs
```

Audio tests need NumPy/SciPy; when missing, run them with
`uv run --with numpy --with scipy python -m unittest discover -s tests -v`.
Tests cover transient detection, silence, delayed audio, media byte ranges,
review persistence, UI outcome/background actions, skip semantics, append-only label
corrections, stale revisions, alignment changes, and LED correspondence validation.

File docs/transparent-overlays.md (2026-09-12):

# Transparent skateboard and sensor overlays

Render the saved video labels as editing-ready graphics:

```bash
uv run viz/render_overlay.py sessions/a7s-001 --video C0642.MP4 \
  --nose-axis x --up-axis=-z --width 1080 --height 1920 \
  --output sessions/a7s-001/overlays/C0642-vertical
```

FFmpeg must be installed (`brew install ffmpeg`). NumPy and Pillow are declared
in the script for `uv`; plain `python3` works when they are already installed.
No browser, display server, Blender, or cloud rendering is required.

The command above exports **1080×1920 vertical video at 30 fps** for DaVinci
Resolve. The upper 840 pixels stay clear; the skateboard sits above three graphs
in the lower part of the frame. Without width/height options, the default is
1920×1080 landscape with the skateboard beside the graphs. The layout switches
automatically for portrait dimensions. Graph panels are
translucent for readability over footage. Each includes a synchronized
playhead, and the motion panels show instantaneous sensor X/Y/Z values. Saved
pop/contact markers and the human trick/outcome label come from the review.
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

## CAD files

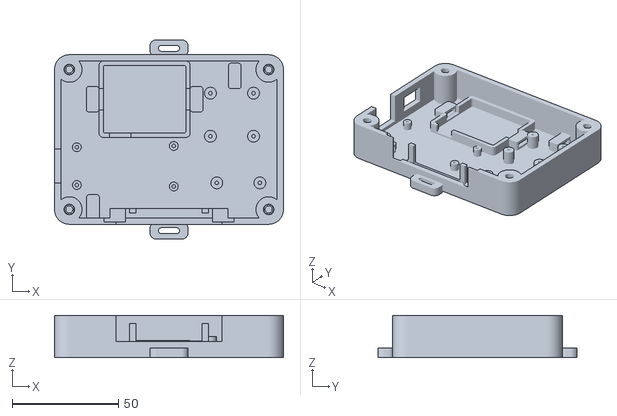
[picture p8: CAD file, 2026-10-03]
hardware/enclosure/exports/base-velcro.stl
108.0 x 94.0 x 20.0

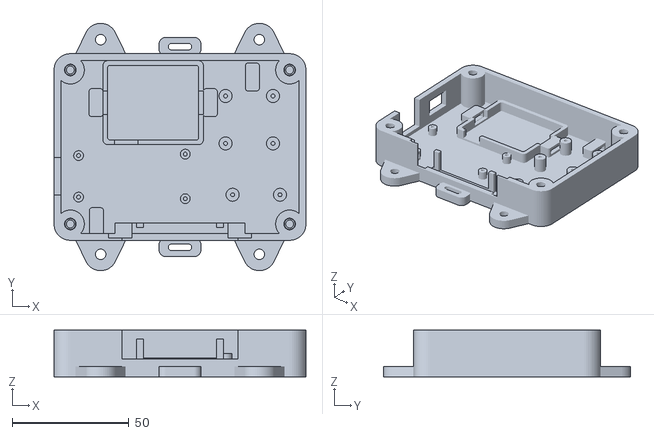
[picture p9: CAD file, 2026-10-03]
hardware/enclosure/exports/base.stl
108.0 x 106.0 x 20.0

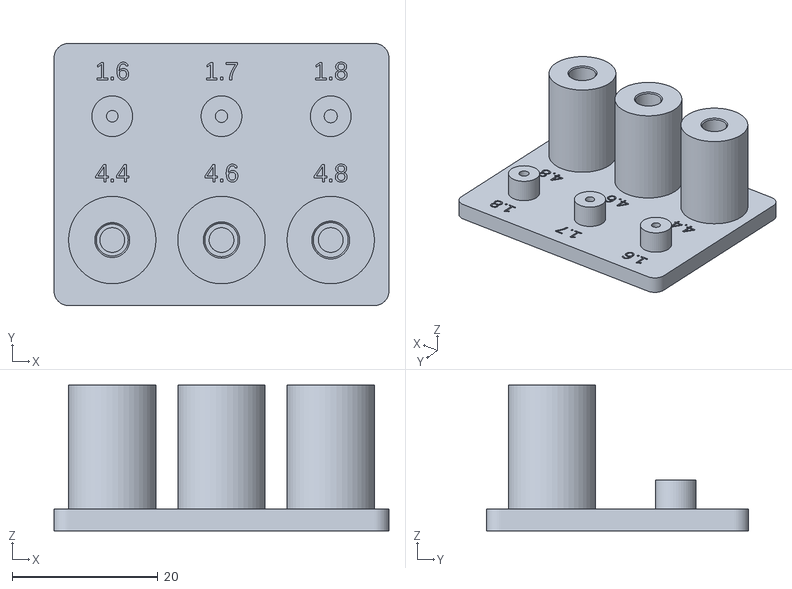
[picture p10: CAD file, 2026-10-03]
hardware/enclosure/exports/fit-coupon.stl
46.0 x 36.0 x 20.0

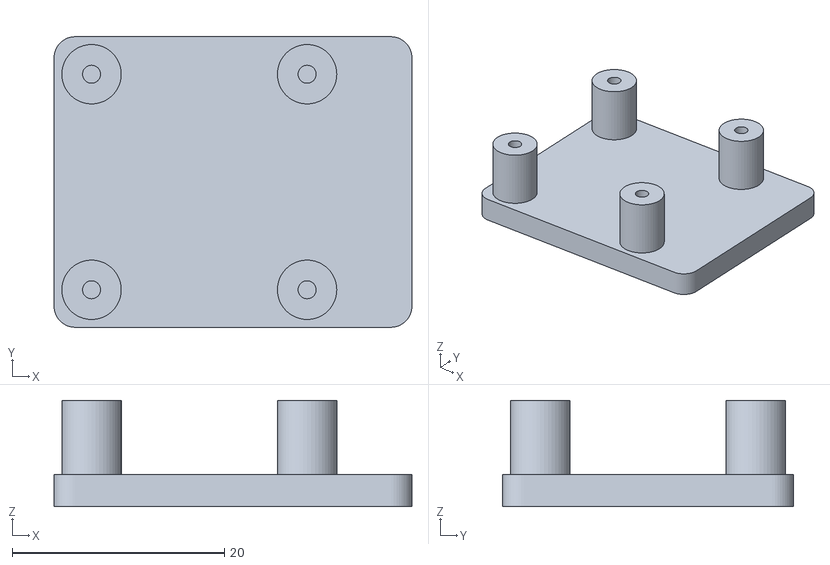
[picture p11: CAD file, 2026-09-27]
hardware/enclosure/exports/sd-fit-base.stl
33.8 x 27.4 x 10.0

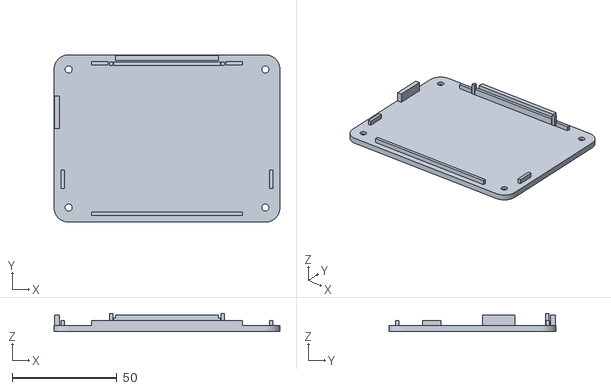
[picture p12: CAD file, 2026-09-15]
hardware/enclosure/exports/lid.stl
108.0 x 80.0 x 8.78

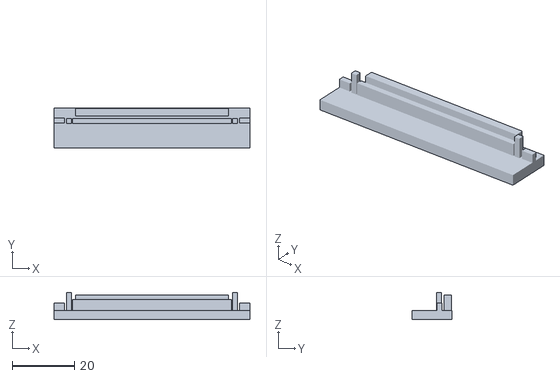
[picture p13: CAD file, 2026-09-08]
hardware/enclosure/exports/led-fit-lid.stl
63.1 x 13.0 x 8.78

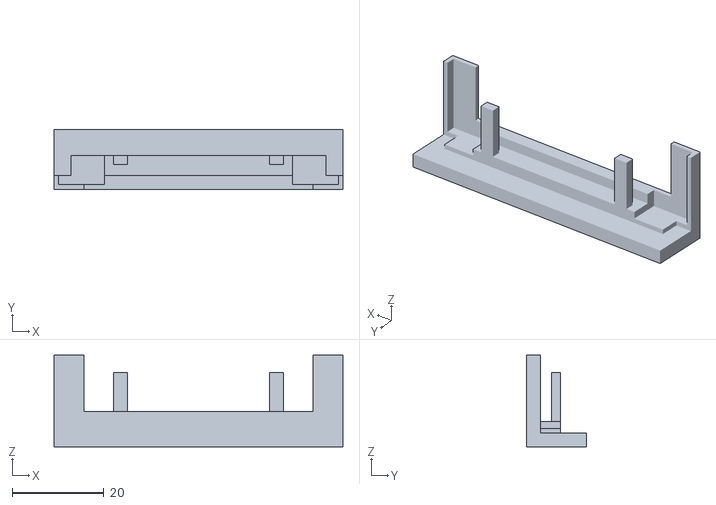
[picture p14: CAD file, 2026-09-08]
hardware/enclosure/exports/led-fit-base.stl
63.1 x 13.0 x 20.0

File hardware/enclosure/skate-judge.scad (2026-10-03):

// Judgy Skateboard: PLA prototype enclosure. Units: mm.
// Revision 8, 2026-10-03: top-loaded M3 heat-set inserts for the lid.
// OpenSCAD 2021.01+. See README.md for hardware, tolerances and assembly.
// PCB coordinates follow Adafruit EagleCAD; component shapes are envelopes.

/* [Output] */
part = "assembly"; // [assembly,exploded,interior,base,lid,fit_coupon,led_fit_base,led_fit_lid,sd_fit_base,layout]
show_electronics = true;
mount_ears = true;
lid_markings = false; // Optional engraving adds first-layer islands and bridges.

/* [Shell] */
case_length = 108;
case_width = 80;
body_height = 20;
wall = 3;
floor_thickness = 3;
lid_thickness = 3;
corner_radius = 7;
fit_clearance = 0.3; // Clearance per side, not total.
mount_hole_diameter = 4.5;

/* [Lid screws] */
lid_countersink_diameter = 6.4; // DIN 7991 M3: 6 mm head + 0.4 mm print allowance.
lid_countersink_angle = 90; // Included bevel angle, in degrees.

/* [Lid heat-set inserts] */
// Jouth M3x4x5 assumed to mean M3 thread, 4 mm length, 5 mm outside diameter.
// Confirm against your inserts; print the bore-size coupon before the base.
lid_insert_length = 4;
lid_insert_outer_diameter = 5;
lid_insert_bore_diameter = 4.6; // Starting fit, not a verified vendor hole specification.
lid_insert_depth_allowance = 1; // Space below a flush insert for displaced plastic.
lid_screw_relief_depth = 10; // From boss top; accepts existing M3x12 countersunk screws.

/* [Battery: measure the complete wrapped cell] */
battery_length = 36;
battery_width = 29;
battery_thickness = 5;
battery_xy_clearance = 1.5;
battery_pad = 0.8;

/* [PCB mounting and ports] */
pcb_standoff = 4;
imu_rotation = 180; // [0,180] In-plane turn only; components stay toward lid.
pcb_pilot_diameter = 1.7; // M2 plastic-compatible screws; print coupon first.
usb_opening_width = 16;
usb_opening_bottom = 5;
usb_opening_top = 15;

/* [Power switch: measured KCD11-101 style body] */
power_switch_width = 13.5; // Along Y; measured body 13.27 mm, allowance included.
power_switch_height = 8.4; // Along Z; measured body 8.18 mm, allowance included.
power_switch_y = 50; // Center on the x=0 USB wall, beside the battery bay.

/* [Adafruit 254 microSD mount] */
sd_standoff = 7; // Above floor; lifts the card's removal path above the battery.
show_sd_clearances = false;

/* [LED stick] */
stick_length = 51.1;
stick_width = 10.22;
stick_height = 3.2;
stick_clearance = 0.3; // End clearance per side in the top-loading channel.
led_lid_clearance = 0.8;
// Open-top wire passages extend this far outward and inward from each PCB end.
led_wire_end_space = 5;
led_wire_pad_space = 5;
// Y bounds of each passage, measured from the exterior long wall.
led_wire_front = 1;
led_wire_back = 11;
// Keep solder/wires below this height above the enclosure back when closing.
led_wire_top = 11.5;
show_led_wire_envelopes = false;

/* [Hidden] */
$fn = 48;
eps = 0.02;
feather_xy = [8,16];
feather_size = [50.8,22.86];
// The rear 2.2 mm holes are NOT the generic Feather 2.54 mm inset pattern.
feather_holes = [[2.54,2.54],[2.54,20.32],[48.26,1.8415],[48.26,20.955]];
imu_xy = [74,17];
imu_size = [25.4,17.78];
imu_native_holes = [[2.54,15.24],[22.86,15.24]];
// Preserve the PCB footprint while moving its screw line 12.7 mm toward LEDs.
imu_holes = imu_rotation == 180
    ? [for(p=imu_native_holes) [imu_size[0]-p[0],imu_size[1]-p[1]]]
    : imu_native_holes;
// Adafruit MicroSD-breakout-board/microsd.brd: NOT four corner insets.
// Both pairs are 20.32 mm apart; the header extends past the right hole pair.
sd_xy = [71,39];
sd_size = [31.75,25.4];
sd_holes = [[2.54,2.54],[2.54,22.86],[22.86,2.54],[22.86,22.86]];
sd_post_diameter = 5.6;
sd_pcb_z = floor_thickness+sd_standoff;
sd_anchor_xy = [85,70];
battery_xy = [23,43]; // Inside lower-left of tray, before clearance.
bay_l = battery_length + 2*battery_xy_clearance;
bay_w = battery_width + 2*battery_xy_clearance;
pcb_z = floor_thickness + pcb_standoff;
usb_y = feather_xy[1]+11.43;
power_switch_bottom = (floor_thickness+body_height-power_switch_height)/2;
lid_screw_clearance = 3.4;
lid_insert_bore_depth = lid_insert_length+lid_insert_depth_allowance;
lid_insert_lead_in = 0.2; // 45-degree entry bevel; default opening is 5.0 mm.
lid_countersink_depth = (lid_countersink_diameter-lid_screw_clearance)/(2*tan(lid_countersink_angle/2));
boss_r = 6;
bosses = [[7,7],[case_length-7,7],[7,case_width-7],[case_length-7,case_width-7]];
ear_xs = [20,case_length-20];
ear_ys = [-6,case_width+6];
led_pcb_thickness = 1.6;
led_x = (case_length-stick_length)/2;
led_bottom = floor_thickness+2.5;
led_slot_x = led_x-stick_clearance;
led_slot_length = stick_length+2*stick_clearance;
led_slot_front = wall+0.2;
led_slot_back = led_slot_front+led_pcb_thickness+2*fit_clearance;
led_window_x = led_x+0.6;
led_window_length = stick_length-1.2;
led_window_bottom = led_bottom+2.2;
led_window_top = led_bottom+stick_width-0.6;
led_anchor_x = led_slot_x-10;
led_top = led_bottom+stick_width;
led_wire_floor = floor_thickness+1;
led_sample_x = led_x-led_wire_end_space-1;
led_sample_length = stick_length+2*led_wire_end_space+2;
led_sample_depth = led_wire_back+2;
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

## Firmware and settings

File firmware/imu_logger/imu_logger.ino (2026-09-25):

// LSM6DSO32 -> hardware FIFO -> RAM queue -> SD (preferred) or LittleFS.
// Acquisition owns the sensor; a separate writer owns the recording file.
#include <Arduino.h>
#include <Wire.h>
#include <WiFi.h>
#include <WebServer.h>
#include <LittleFS.h>
#include <Adafruit_NeoPixel.h>
#include <esp_timer.h>
#include <esp_partition.h>
#include <driver/gpio.h>
#include <esp32-hal-periman.h>
#include <sys/stat.h>
#include <fcntl.h>
#include <unistd.h>
#include "log_format.h"
#include "battery_monitor.h"

#ifndef IMU_SDA
#define IMU_SDA 3
#endif
#ifndef IMU_SCL
#define IMU_SCL 4
#endif
#ifndef IMU_POWER
#define IMU_POWER 7
#endif
#ifndef SYNC_LED_PIN
#define SYNC_LED_PIN 5
#endif
#ifndef SYNC_LED_COUNT
#define SYNC_LED_COUNT 8
#endif
#ifndef SYNC_LED_BRIGHTNESS
#define SYNC_LED_BRIGHTNESS 255
#endif
#ifndef SYNC_LED_RGBW
#define SYNC_LED_RGBW 0
#endif

static constexpr uint32_t RESERVE_BYTES = 32768; // Footer and filesystem headroom.
static constexpr uint16_t FIFO_BYTES = 896; // 128 raw tagged FIFO words.
#include "log_storage.h"
static Adafruit_NeoPixel pixels(SYNC_LED_COUNT, SYNC_LED_PIN,
  (SYNC_LED_RGBW ? NEO_GRBW : NEO_GRB) + NEO_KHZ800);
static WebServer server(80);
static uint32_t bootId;
static uint8_t sensorAddress = 0;
static int idleSda = -1, idleScl = -1;
static bool ledReady = false;
static bool storageReady = false;
static bool usbRequest = false;
static String usbQuery;
static portMUX_TYPE stateMux = portMUX_INITIALIZER_UNLOCKED;
enum Phase { IDLE, STARTING, RECORDING, STOPPING, SAVED, FAULT, TESTING_LED };
struct State {
  Phase phase = IDLE;
  char id[33] = {};
  const char *error = "";
  bool sensorReady = false;
  uint32_t accel = 0, gyro = 0, zeroAccel = 0, ioErrors = 0, fifoOverruns = 0, busRetries = 0;
  uint64_t bytes = 0, freeBytes = 0;
  uint32_t marker = 0, queuePeak = 0;
  uint32_t ledTests = 0;
  int batteryBeforeMv = -1, batteryOnMv = -1, ledRmtReady = -1;
  BatteryReading battery;
  uint64_t batteryCheckedUs = 0;
  uint64_t startedUs = 0, endedUs = 0, lastSyncUs = 0;
  float accelHz = 0, gyroHz = 0;
};
static State state;
enum Action { START, STOP, FLASH, CHECK_SENSOR, TEST_LED };
struct Command { Action action; char id[33]; uint32_t marker; };
static State snapshot() {
  portENTER_CRITICAL(&stateMux); State copy = state; portEXIT_CRITICAL(&stateMux); return copy;
}
static void publish(const State &s) {
  portENTER_CRITICAL(&stateMux); state = s; portEXIT_CRITICAL(&stateMux);
}
static QueueHandle_t commands;
static char sensorError[112] = "sensor_not_found_check_cable_and_power";

// A short/failed read never leaves uninitialized bytes masquerading as motion.
static bool readReg(uint8_t address, uint8_t reg, uint8_t *data, size_t count) {
  Wire.beginTransmission(address); Wire.write(reg);
  uint8_t error = Wire.endTransmission(false);
  if (error != 0) {
    snprintf(sensorError, sizeof(sensorError), "i2c_address_%02x_reg_%02x_error_%u", address, reg, error);
    return false;
  }
  size_t received = Wire.requestFrom(address, count, true);
  if (received != count) {
    snprintf(sensorError, sizeof(sensorError), "i2c_address_%02x_reg_%02x_short_read_%u_of_%u", address, reg, unsigned(received), unsigned(count));
    while (Wire.available()) Wire.read();
    return false;
  }
  for (size_t i = 0; i < count; ++i) data[i] = Wire.read();
  return true;
}
static bool writeReg(uint8_t reg, uint8_t value) {
  Wire.beginTransmission(sensorAddress); Wire.write(reg); Wire.write(value);
  uint8_t error = Wire.endTransmission();
  if (error) snprintf(sensorError, sizeof(sensorError), "i2c_write_reg_%02x_error_%u", reg, error);
  return error == 0;
}
static bool checkedWrite(uint8_t reg, uint8_t value) {
  uint8_t actual = 0;
  if (!writeReg(reg, value) || !readReg(sensorAddress, reg, &actual, 1)) return false;
  if (actual != value) {
    snprintf(sensorError, sizeof(sensorError), "sensor_reg_%02x_expected_%02x_read_%02x", reg, value, actual);
    return false;
  }
  return true;
}
static bool setupSensor() {
  sensorAddress = 0;
  Wire.end();
  if (IMU_POWER >= 0) {
    pinMode(IMU_POWER, OUTPUT); digitalWrite(IMU_POWER, LOW);
    delay(100); digitalWrite(IMU_POWER, HIGH);
  }
  delay(100);
  // Inspect released lines before the I2C peripheral can drive them. A line
  // held low here is a bus/power problem, not a missing WHO_AM_I register.
  pinMode(IMU_SDA, INPUT_PULLUP); pinMode(IMU_SCL, INPUT_PULLUP);
  delay(2);
  idleSda = gpio_get_level(gpio_num_t(IMU_SDA));
  idleScl = gpio_get_level(gpio_num_t(IMU_SCL));
  if (!idleScl || !idleSda) {
    snprintf(sensorError, sizeof(sensorError), "i2c_bus_held_low_sda_%d_scl_%d_check_cable_sensor_and_power", idleSda, idleScl);
    return false;
  }
  // Use the sensor's supported fast-mode bus to leave acquisition headroom.
  // FIFO buffering absorbs a delayed transaction; a failed read still faults.
  if (!Wire.begin(IMU_SDA, IMU_SCL, 400000)) return false;
  Wire.setTimeOut(50);
  for (uint8_t address : {0x6a, 0x6b}) {
    uint8_t who = 0;
    if (readReg(address, 0x0f, &who, 1)) {
      if (who == 0x6c) { sensorAddress = address; break; }
      snprintf(sensorError, sizeof(sensorError), "unexpected_sensor_id_%02x_at_%02x", who, address);
    }
  }
  if (!sensorAddress || !writeReg(0x12, 0x01)) return false;
  uint8_t reset = 1;
  for (int i = 0; i < 50 && (reset & 1); ++i) {
    delay(1); if (!readReg(sensorAddress, 0x12, &reset, 1)) return false;
  }
  if (reset & 1) return false;
  // Datasheet: BDU + auto-increment, 208 Hz, ±32 g, ±2000 dps,
  // I3C disabled, timestamp enabled. Check every configuration readback.
  return checkedWrite(0x12, 0x44) && checkedWrite(0x18, 0x02) &&
    checkedWrite(0x10, 0x54) && checkedWrite(0x11, 0x5c) &&
    checkedWrite(0x19, 0x20) && checkedWrite(0x08, 0) &&
    checkedWrite(0x09, 0) && checkedWrite(0x0a, 0);
}

static uint32_t packetSequence = 0;
static uint8_t fifoBuffer[FIFO_BYTES];
static uint16_t fifoUsed = 0;
static bool fifoDiscarded = false;
static uint8_t fifoSlotCounter = 0xff, fifoSlotKinds = 0;
static bool writePacket(State &s, uint8_t kind, uint64_t stamp, const void *payload, size_t size) {
  WriterStatus writer = writerSnapshot();
  if (!writer.open || *writer.error) { s.error = *writer.error ? writer.error : "log_not_open"; return false; }
  // FAT32 files are limited to 4 GiB. Leave room for the stop/footer packets.
  if (s.bytes + sizeof(LogHeader) + size >= 0xffffffffULL - RESERVE_BYTES && kind != END) {
    s.error = "recording_file_size_limit"; return false;
  }
  LogHeader header = logHeader(kind, size, packetSequence, stamp, payload);
  if (!logQueue.push(&header, sizeof(header), payload, size)) { s.error = "storage_buffer_full"; return false; }
  ++packetSequence;
  s.queuePeak = max(s.queuePeak, uint32_t(logQueue.used()));
  s.bytes += sizeof(header) + size;
  return true;
}
static bool flushFIFO(State &s) {
  if (!fifoUsed) return true;
  bool ok = writePacket(s, FIFO, esp_timer_get_time(), fifoBuffer, fifoUsed);
  if (!ok) fifoDiscarded = true;
  fifoUsed = 0;
  return ok;
}
static bool durable(State &s) {
  bool ok = writerControl(SYNC_LOG);
  WriterStatus writer = writerSnapshot();
  s.freeBytes = writer.freeBytes;
  if (!ok && !*s.error) s.error = writer.error;
  return ok;
}
static bool clockAnchor(State &s) {
  uint8_t payload[12];
  uint64_t before = esp_timer_get_time();
  bool ok = readReg(sensorAddress, 0x40, payload + 8, 4);
  uint64_t after = esp_timer_get_time();
  if (!ok) { ++s.ioErrors; s.error = "timestamp_read_failed"; return false; }
  memcpy(payload, &after, 8);
  return flushFIFO(s) && writePacket(s, CLOCK, before, payload, sizeof(payload));
}
static bool peekFIFO(State &s, uint8_t *tag) {
  // Reading the tag does not consume a FIFO word. Retry this operation only;
  // arbitrary replay of the consuming payload read could lose a sample.
  for (int attempt = 0; attempt < 3; ++attempt) {
    if (readReg(sensorAddress, 0x78, tag, 1)) return true;
    if (attempt < 2) { ++s.busRetries; delay(1); }
  }
  return false;
}
static bool readFIFOWord(State &s, uint8_t *word) {
  if (!peekFIFO(s, word)) return false;
  for (int attempt = 0; attempt < 3; ++attempt) {
    if (readReg(sensorAddress, 0x79, word + 1, 6)) return true;
    uint8_t head = 0;
    // All configured words in a slot have distinct tags. If the head moved,
    // the failed transfer consumed data, so stop rather than skipping it.
    if (attempt == 2 || !peekFIFO(s, &head) || head != word[0]) return false;
    ++s.busRetries; delay(1);
  }
  return false;
}
static bool drainFIFO(State &s) {
  uint8_t status[2];
  if (!readReg(sensorAddress, 0x3a, status, 2)) {
    ++s.ioErrors; s.error = "fifo_status_read_failed"; return false;
  }
  // FIFO mode stops at full rather than overwriting unread data. Either full
  // or overrun means sampling continuity was lost; report and close the log.
  const bool full = status[1] & 0x68;
  if (full) { ++s.fifoOverruns; s.error = "fifo_full_or_overrun"; }
  uint16_t count = status[0] | ((status[1] & 3) << 8);
  for (uint16_t i = 0; i < count; ++i) {
    if (fifoUsed + 7 > FIFO_BYTES && !flushFIFO(s)) return false;
    uint8_t *word = fifoBuffer + fifoUsed;
    // Read the tag separately from the six FIFO output registers. This keeps
    // tag access outside the burst that consumes the FIFO word.
    if (!readFIFOWord(s, word)) {
      ++s.ioErrors; s.error = "fifo_data_read_failed"; return false;
    }
    const uint8_t tag = word[0] >> 3;
    if (__builtin_parity(unsigned(word[0]))) {
      ++s.ioErrors; s.error = "fifo_tag_parity_failed"; return false;
    }
    if (tag != 1 && tag != 2 && tag != 3 && tag != 4) {
      ++s.ioErrors; s.error = "unexpected_fifo_tag"; return false;
    }
    const uint8_t counter = (word[0] >> 1) & 3;
    if (counter != fifoSlotCounter) { fifoSlotCounter = counter; fifoSlotKinds = 0; }
    if (fifoSlotKinds & (1 << tag)) {
      ++s.ioErrors; s.error = "duplicate_fifo_word_in_time_slot"; return false;
    }
    fifoSlotKinds |= 1 << tag;
    if (tag == 1) ++s.gyro;
    if (tag == 2) {
      ++s.accel;
      if (!(word[1] | word[2] | word[3] | word[4] | word[5] | word[6])) ++s.zeroAccel;
    }
    fifoUsed += 7;
  }
  return !full;
}
static void led(bool on) {
  pixels.fill(on ? (SYNC_LED_RGBW ? pixels.Color(0, 0, 0, SYNC_LED_BRIGHTNESS)
    : pixels.Color(SYNC_LED_BRIGHTNESS, SYNC_LED_BRIGHTNESS, SYNC_LED_BRIGHTNESS)) : 0);
  pixels.show();
}
static BatteryReading readBattery() {
  // Acquisition owns Wire. Bound optional gauge reads so an absent/faulty
  // gauge cannot hold up FIFO draining; restore the IMU timeout afterwards.
  uint16_t timeout = Wire.getTimeOut();
  Wire.setTimeOut(5);
  auto readWord = [](uint8_t reg) -> int {
    Wire.beginTransmission(0x36); Wire.write(reg);
    if (Wire.endTransmission(false) != 0) return -1;
    if (Wire.requestFrom(uint8_t(0x36), size_t(2), true) != 2) {
      while (Wire.available()) Wire.read();
      return -1;
    }
    int high = Wire.read();
    return (high << 8) | Wire.read();
  };
  BatteryReading reading = readMAX17048(readWord);
  Wire.setTimeOut(timeout);
  return reading;
}
static bool syncEdge(State &s, uint32_t marker, bool on) {
  uint8_t payload[6]; memcpy(payload, &marker, 4); payload[4] = on; payload[5] = ledReady;
  const uint64_t stamp = esp_timer_get_time();
  led(on);
  if (on) { s.marker = marker; s.lastSyncUs = stamp; }
  return flushFIFO(s) && writePacket(s, SYNC, stamp, payload, sizeof(payload));
}
static void stopLog(State &s, bool &lit) {
  const char *firstError = s.error;
  char firstBusError[sizeof(sensorError)];
  snprintf(firstBusError, sizeof(firstBusError), "%s", sensorError);
  s.phase = STOPPING; publish(s);
  if (!writeReg(0x09, 0)) { ++s.ioErrors; s.error = "fifo_stop_failed"; }
  if (lit) { syncEdge(s, s.marker, false); lit = false; }
  drainFIFO(s); flushFIFO(s); clockAnchor(s);
  s.endedUs = esp_timer_get_time();
  durable(s); // Batching is stopped; drain the queue before writing the footer.
  if (*firstError) s.error = firstError; // Keep the cause, not a cleanup failure.
  WriterStatus writer = writerSnapshot();
  char diagnostics[320];
  writer.diagnostics.json(diagnostics, sizeof(diagnostics), writer.written);
  char footer[897]; // END payload shares the decoder's 896-byte packet bound.
  snprintf(footer, sizeof(footer),
    "{\"accel_samples\":%lu,\"gyro_samples\":%lu,\"zero_accel\":%lu,\"io_errors\":%lu,\"fifo_overruns\":%lu,\"bus_retries\":%lu,\"error\":\"%s\",\"bus_error\":\"%s\",\"storage_queue_peak_bytes\":%lu,\"storage_max_write_us\":%lu,\"storage_max_flush_us\":%lu,\"storage_recoveries\":%lu,\"storage_recovery_attempts\":%lu,\"storage_diagnostics\":%s}",
    (unsigned long)s.accel, (unsigned long)s.gyro, (unsigned long)s.zeroAccel,
    (unsigned long)s.ioErrors, (unsigned long)s.fifoOverruns, (unsigned long)s.busRetries, s.error, s.ioErrors ? firstBusError : "",
    (unsigned long)s.queuePeak, (unsigned long)writer.maxWriteUs, (unsigned long)writer.maxFlushUs,
    (unsigned long)writer.recoveries, (unsigned long)writer.recoveryAttempts, diagnostics);
  // If backpressure discarded raw words, do not claim a complete log with
  // sample counts that cannot match it. Intact packets remain recoverable via
  // --allow-incomplete; the host also retains the board's stop error.
  if (!fifoDiscarded) writePacket(s, END, s.endedUs, footer, strlen(footer));
  if (!writerControl(CLOSE_LOG) && !*s.error) s.error = writerSnapshot().error;
  s.freeBytes = writerSnapshot().freeBytes;
  if (*firstError) s.error = firstError;
  writeReg(0x0a, 0);
  s.phase = *s.error ? FAULT : SAVED; publish(s);
}
static bool startLog(State &s, const Command &command) {
  BatteryReading battery = s.battery;
  uint64_t batteryCheckedUs = s.batteryCheckedUs;
  s = State(); s.sensorReady = true; s.phase = STARTING;
  s.battery = battery; s.batteryCheckedUs = batteryCheckedUs;
  memcpy(s.id, command.id, sizeof(s.id)); publish(s);
  if (!storageReady) { s.error = "initialize_storage_first"; return false; }
  s.freeBytes = recordingStorage->freeBytes();
  if (s.freeBytes < RESERVE_BYTES + 65536) { s.error = "insufficient_storage_space"; return false; }
  uint8_t temp[2], frequencyFine;
  if (!checkedWrite(0x12, 0x44) || !checkedWrite(0x18, 0x02) ||
      !checkedWrite(0x10, 0x54) || !checkedWrite(0x11, 0x5c) || !checkedWrite(0x19, 0x20) ||
      !readReg(sensorAddress, 0x20, temp, 2) || !readReg(sensorAddress, 0x63, &frequencyFine, 1) ||
      !checkedWrite(0x09, 0) || !checkedWrite(0x0a, 0)) {
    ++s.ioErrors; s.error = "sensor_preflight_failed"; return false;
  }
  logQueue.reset();
  String path = String(recordingStorage->mount) + recordingStorage->path(s.id);
  if (!writerControl(OPEN_LOG, path.c_str())) { s.error = writerSnapshot().error; return false; }
  fifoUsed = 0; fifoDiscarded = false; packetSequence = 0;
  fifoSlotCounter = 0xff; fifoSlotKinds = 0;
  s.startedUs = esp_timer_get_time();
  int16_t rawTemp = int16_t(uint16_t(temp[0]) | (uint16_t(temp[1]) << 8));
  char meta[560];
  snprintf(meta, sizeof(meta),
    "{\"schema\":1,\"id\":\"%s\",\"boot_id\":\"%08lx\",\"sensor\":\"LSM6DSO32\",\"odr_hz\":208,\"accel_g_per_lsb\":0.000976,\"gyro_dps_per_lsb\":0.070,\"timestamp_tick_us\":25,\"frequency_fine\":%d,\"initial_temp_C\":%.4f,\"flash_bytes\":%lu,\"psram_bytes\":%lu,\"storage\":\"%s\",\"storage_diagnostics_version\":2,\"sd_spi_hz\":%u}",
    s.id, (unsigned long)bootId, int(int8_t(frequencyFine)), 25.0 + rawTemp / 256.0,
    (unsigned long)ESP.getFlashChipSize(), (unsigned long)ESP.getPsramSize(), recordingStorage->name, unsigned(SD_SPI_HZ));
  if (!writePacket(s, META, s.startedUs, meta, strlen(meta)) || !clockAnchor(s) || !durable(s)) return false;
  // 208 Hz accel + gyro batching, timestamp every slot, temperature 1.6 Hz,
  // stop-on-full FIFO. The sensor continues sampling during ESP32 flash writes.
  if (!checkedWrite(0x09, 0x55) || !checkedWrite(0x0a, 0x51)) {
    ++s.ioErrors; s.error = "fifo_configuration_failed"; return false;
  }
  s.startedUs = esp_timer_get_time(); s.phase = RECORDING; publish(s); return true;
}
static void acquire(void *) {
  State s = snapshot();
  s.sensorReady = setupSensor();
  if (!s.sensorReady) s.error = sensorError;
  publish(s);
  bool lit = false;
  uint64_t lastBatch = 0, lastClock = 0, rateAt = 0;
  uint32_t previousAccel = 0, previousGyro = 0;
  for (;;) {
    Command cmd;
    while (xQueueReceive(commands, &cmd, 0) == pdTRUE) {
      // Idle initialize/delete requests may have refreshed available space.
      s.freeBytes = snapshot().freeBytes;
      if (cmd.action == TEST_LED && ledReady &&
          (s.phase == IDLE || s.phase == SAVED || s.phase == FAULT)) {
        // This task owns LED writes. Test only while idle; never add fake sync
        // markers or touch a saved recording. Leave LEDs off when finished.
        Phase previous = s.phase;
        s.phase = TESTING_LED; publish(s);
        s.batteryBeforeMv = readBattery().millivolts;
        s.batteryOnMv = -1; s.ledRmtReady = 1;
        for (int i = 0; i < 3; ++i) {
          led(true); vTaskDelay(pdMS_TO_TICKS(1000));
          s.ledRmtReady &= perimanGetPinBus(SYNC_LED_PIN, ESP32_BUS_TYPE_RMT_TX) != nullptr &&
                           rmtTransmitCompleted(SYNC_LED_PIN);
          if (i == 0) s.batteryOnMv = readBattery().millivolts;
          led(false); vTaskDelay(pdMS_TO_TICKS(1000));
        }
        ++s.ledTests; s.phase = previous; publish(s);
      } else if (cmd.action == CHECK_SENSOR && s.phase != RECORDING && s.phase != STOPPING) {
        s.phase = STARTING; publish(s);
        s.sensorReady = setupSensor();
        s.error = s.sensorReady ? "" : sensorError;
        s.phase = IDLE; publish(s);
      } else if (cmd.action == START && s.phase != RECORDING && s.phase != STOPPING) {
        // Do not reset the sensor or reopen a log on a retried start request.
        if (!strcmp(s.id, cmd.id)) continue;
        if (!s.sensorReady || !startLog(s, cmd)) {
          if (writerSnapshot().open) stopLog(s, lit);
          else { s.phase = FAULT; publish(s); }
        } else {
          lastBatch = lastClock = rateAt = s.startedUs;
          previousAccel = previousGyro = 0;
        }
      } else if (cmd.action == STOP && s.phase == RECORDING && !strcmp(cmd.id, s.id)) {
        stopLog(s, lit);
      } else if (cmd.action == FLASH && s.phase == RECORDING && !strcmp(cmd.id, s.id) && cmd.marker > s.marker && !lit) {
        if (!ledReady) { s.error = "sync_led_unavailable"; stopLog(s, lit); }
        else if (syncEdge(s, cmd.marker, true)) { lit = true; publish(s); }
        else stopLog(s, lit);
      }
    }
    if (s.phase == RECORDING) {
      const uint64_t now = esp_timer_get_time();
      bool ok = true;
      if (lit && now - s.lastSyncUs >= 150000) { ok = syncEdge(s, s.marker, false); lit = false; }
      ok = ok && drainFIFO(s);
      if (now - lastBatch >= 50000) { ok = ok && flushFIFO(s); lastBatch = now; }
      if (now - lastClock >= 1000000) { ok = ok && clockAnchor(s); lastClock = now; }
      WriterStatus writer = writerSnapshot();
      s.freeBytes = writer.freeBytes;
      if (*writer.error) { s.error = writer.error; ok = false; }
      if (now - rateAt >= 1000000) {
        s.accelHz = (s.accel - previousAccel) * 1e6 / (now - rateAt);
        s.gyroHz = (s.gyro - previousGyro) * 1e6 / (now - rateAt);
        previousAccel = s.accel; previousGyro = s.gyro; rateAt = now;
        if (now - s.startedUs > 3000000 && (s.accelHz < 180 || s.gyroHz < 180)) {
          s.error = "sample_rate_below_180_hz"; ok = false;
        }
        if (s.accel >= 400 && s.zeroAccel > s.accel / 4) {
          s.error = "excessive_zero_acceleration_check_sensor"; ok = false;
        }
      }
      if (s.freeBytes <= RESERVE_BYTES && !*s.error) { s.error = "storage_capacity_reached"; ok = false; }
      if (!ok) stopLog(s, lit);
      else publish(s);
    }
    // Drain motion first, and defer gauge reads while a sync pulse is lit.
    // These reads never contribute to sensor error counters or stop a log.
    const uint64_t batteryNow = esp_timer_get_time();
    if (!lit && (!s.batteryCheckedUs || batteryNow - s.batteryCheckedUs >= 5000000)) {
      s.battery = readBattery();
      s.batteryCheckedUs = esp_timer_get_time();
      publish(s);
    }
    vTaskDelay(pdMS_TO_TICKS(5));
  }
}

static bool validId(const String &id) {
  if (id.length() != 32) return false;
  for (char c : id) if (!((c >= '0' && c <= '9') || (c >= 'a' && c <= 'f'))) return false;
  return true;
}
static String parameter(const char *name) {
  if (!usbRequest) return server.arg(name);
  String prefix = String(name) + "=";
  int begin = 0;
  while (begin <= int(usbQuery.length())) {
    int end = usbQuery.indexOf('&', begin);
    if (end < 0) end = usbQuery.length();
    String field = usbQuery.substring(begin, end);
    if (field.startsWith(prefix)) return field.substring(prefix.length());
    begin = end + 1;
  }
  return "";
}
static void reply(int code, const char *type, const String &body) {
  if (usbRequest) {
    Serial.printf("{\"status\":%d,\"body\":", code); Serial.print(body); Serial.println("}");
  } else server.send(code, type, body);
}
static void errorResponse(int code, const char *error) {
  reply(code, "application/json", String("{\"error\":\"") + error + "\"}");
}
static bool idleOnly() {
  Phase phase = snapshot().phase;
  if (phase == RECORDING || phase == STARTING || phase == STOPPING || phase == TESTING_LED || uxQueueMessagesWaiting(commands)) {
    errorResponse(409, "Board is busy; stop recording or wait for the current operation."); return false;
  }
  return true;
}
static bool controlAllowed() {
  if (!usbRequest && server.hasHeader("Origin") && server.header("Origin").length()) {
    errorResponse(403, "Use the local laptop recorder."); return false;
  }
  return true;
}
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
void loop() {
  server.handleClient();
  pollUSB();
  delay(1);
}

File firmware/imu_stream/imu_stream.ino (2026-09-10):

// imu_stream.ino
//
// Streams LSM6DSO32 accelerometer + gyroscope samples over USB serial for
// viz/imu_viz.py.  Output, 100 lines per second:
//
//   D,<device_us>,<ax>,<ay>,<az>,<gx>,<gy>,<gz>,<temp_C>,<sequence>,<boot_id>
//                                                     accel m/s^2, gyro rad/s
//   R,<accel_sat_ms2>,<gyro_sat_rads>                   where the int16 readings saturate
//   I,<text>                                            informational
//   E,<text>                                            error
//
// Send "i" (or "?") to get the info lines again.
// Send "s" for a timestamped 150 ms LED sync pulse. New D lines append a
// sequence number and boot ID; the orientation viewer ignores these fields.
// For an eight-pixel SKC6812 RGB stick, set SYNC_LED_RGB=1, SYNC_LED_COUNT=8,
// and SYNC_LED_PIN to its data GPIO. SYNC_LED_RGBW=1 selects a GRBW stick.
// Optional SKATE_WIFI=1 starts a local AP and streams UDP to a subscribing
// recorder on port 5050. USB remains available.
//
// The sketch does not assume a particular ESP32-S3 board: it tries the usual
// STEMMA QT / Qwiic I2C pin pairs until it finds the sensor.  To force a pair,
// build with  -DIMU_SDA=<pin> -DIMU_SCL=<pin> [-DIMU_POWER=<pin>]  (flash.sh reads
// IMU_SDA / IMU_SCL / IMU_POWER from the environment and does this for you).

#include <Wire.h>
#include <Adafruit_LSM6DSO32.h>
#include <esp_timer.h>
#include <esp_system.h>
#include <driver/gpio.h>
#include <stdarg.h>

#ifndef SKATE_WIFI
#define SKATE_WIFI 0
#endif
#ifndef SYNC_LED_PIN
#define SYNC_LED_PIN -1
#endif
#ifndef SYNC_LED_RGB
#define SYNC_LED_RGB 0
#endif
#ifndef SYNC_LED_ACTIVE_LOW
#define SYNC_LED_ACTIVE_LOW 0
#endif
#ifndef SYNC_LED_RGBW
#define SYNC_LED_RGBW 0
#endif
#ifndef SYNC_LED_COUNT
#define SYNC_LED_COUNT 1
#endif
#ifndef SYNC_LED_BRIGHTNESS
#define SYNC_LED_BRIGHTNESS 255  // maximum PWM channel value for visible sync flashes
#endif

#if SYNC_LED_RGB || SYNC_LED_RGBW
#if SYNC_LED_COUNT < 1 || SYNC_LED_COUNT > 64
#error "SYNC_LED_COUNT must be between 1 and 64"
#endif
#if SYNC_LED_BRIGHTNESS < 1 || SYNC_LED_BRIGHTNESS > 255
#error "SYNC_LED_BRIGHTNESS must be between 1 and 255"
#endif
#if SYNC_LED_PIN >= 0
#include <Adafruit_NeoPixel.h>
static Adafruit_NeoPixel syncPixels(SYNC_LED_COUNT, SYNC_LED_PIN,
                                   (SYNC_LED_RGBW ? NEO_GRBW : NEO_GRB) + NEO_KHZ800);
#endif
#endif

#if SKATE_WIFI
#include <WiFi.h>
#include <NetworkUdp.h>
static NetworkUDP udp;
static IPAddress recorderIP;
static uint16_t recorderPort = 0;
static uint32_t lastHeartbeat = 0;
static bool wifiReady = false;
static char apName[32];
#endif

static uint32_t bootId;
static uint32_t sampleSequence = 0;
static uint32_t syncSequence = 0;
static bool syncOn = false;
static bool ledReady = false;
static int64_t syncOffAt = 0;

static void emit(const char *format, ...) {
  char line[240];
  va_list args;
  va_start(args, format);
  vsnprintf(line, sizeof(line), format, args);
  va_end(args);
  if (Serial) Serial.print(line);
#if SKATE_WIFI
  if (wifiReady && recorderPort && millis() - lastHeartbeat < 5000) {
    if (udp.beginPacket(recorderIP, recorderPort)) {
      udp.write((const uint8_t *)line, strlen(line));
      udp.endPacket();
    }
  }
#endif
}

static void setSyncLED(bool on) {
  if (!ledReady) return;
#if SYNC_LED_PIN >= 0
#if SYNC_LED_RGB || SYNC_LED_RGBW
  // Fill the whole chain, then latch one frame so all eight pixels flash
  // together. RGBW sticks use their dedicated white channel.
  uint8_t level = on ? SYNC_LED_BRIGHTNESS : 0;
  uint32_t color = SYNC_LED_RGBW ? syncPixels.Color(0, 0, 0, level)
                               : syncPixels.Color(level, level, level);
  syncPixels.fill(color);
  syncPixels.show();
#else
  digitalWrite(SYNC_LED_PIN, on != (bool)SYNC_LED_ACTIVE_LOW ? HIGH : LOW);
#endif
#endif
}

static void syncEdge(bool on) {
  // Timestamp the physical operation, before USB/network output can delay it.
  int64_t at = esp_timer_get_time();
  setSyncLED(on);
  syncOn = on;
  if (on) syncOffAt = at + 150000;
  emit("S,%llu,%lu,%d,%d,%08lx\n", (unsigned long long)at,
       (unsigned long)syncSequence, on ? 1 : 0, ledReady ? 1 : 0,
       (unsigned long)bootId);
}

#ifndef IMU_SDA
#define IMU_SDA -1
#endif
#ifndef IMU_SCL
#define IMU_SCL -1
#endif
#ifndef IMU_POWER
#define IMU_POWER -1
#endif

static const uint32_t SAMPLE_PERIOD_US = 10000;  // 100 Hz stream

// Where the raw int16 readings saturate for the ranges set in configureSensor():
// 0.976 mg/LSB at +/-32 g, 70 mdps/LSB at +/-2000 dps (the "2000" is nominal).
static const float ACCEL_SAT_MS2 = 32767.0f * 0.976e-3f * 9.80665f;  // ~313.6 m/s^2 (~32 g)
static const float GYRO_SAT_RADS = 32767.0f * 0.070f * DEG_TO_RAD;   // ~40.0 rad/s (~2294 dps)

struct PinPair {
  int8_t sda;
  int8_t scl;
  int8_t power;  // GPIO that must be HIGH to power the STEMMA QT port (Adafruit Feathers), or -1
  const char *note;
};

// Pins 19/20 (USB), 26-37 (flash/PSRAM) and 43/44 (UART0) are deliberately absent.
static const PinPair CANDIDATES[] = {
  { IMU_SDA, IMU_SCL, IMU_POWER, "build flags" },
  { SDA,     SCL,     -1, "board default" },
  { 3,  4,   7, "Adafruit Feather ESP32-S3 / Reverse TFT, I2C power on GPIO 7" },
  { 42, 41, 21, "Adafruit Feather ESP32-S3 TFT, I2C power on GPIO 21" },
  { 8,  9,  -1, "ESP32-S3 DevKitC / SparkFun Thing Plus / Unexpected Maker" },
  { 41, 40, -1, "Adafruit QT Py ESP32-S3 STEMMA QT port" },
  { 5,  6,  -1, "Seeed XIAO ESP32S3" },
  { 1,  2,  -1, "DFRobot FireBeetle 2 ESP32-S3" },
  { 47, 48, -1, "Adafruit Metro ESP32-S3" },
};
static const uint8_t ADDRESSES[] = { 0x6A, 0x6B };  // 0x6B when the DO/SDO jumper is closed

Adafruit_LSM6DSO32 imu;
static bool        found     = false;
static int         foundSda  = -1;
static int         foundScl  = -1;
static uint8_t     foundAddr = 0;
static const char *foundNote = "";

static void printInfo() {
  emit("I,imu_stream on %s; boot=%08lx; protocol=2\n", ARDUINO_BOARD, (unsigned long)bootId);
  if (found) {
    emit("I,LSM6DSO32 at 0x%02X on SDA=%d SCL=%d (%s)\n", foundAddr, foundSda, foundScl, foundNote);
    emit("I,accel +/-32 g, gyro +/-2000 dps, 208 Hz ODR, 100 Hz stream\n");
    emit("R,%.2f,%.4f\n", ACCEL_SAT_MS2, GYRO_SAT_RADS);
  } else {
    emit("E,no LSM6DSO32 found on any candidate I2C pins\n");
  }
  emit("I,sync LED pin=%d rgb=%d rgbw=%d pixels=%d brightness=%d enabled=%d\n",
       SYNC_LED_PIN, SYNC_LED_RGB, SYNC_LED_RGBW, SYNC_LED_COUNT,
       SYNC_LED_BRIGHTNESS, ledReady ? 1 : 0);
#if SKATE_WIFI
  if (wifiReady) emit("I,WiFi AP=%s; UDP=192.168.4.1:5050\n", apName);
  else emit("E,WiFi AP or UDP initialization failed\n");
#endif
}

static void command(int c) {
  if (c == 'i' || c == '?') printInfo();
  if (c == 's' && !syncOn) {
    ++syncSequence;
    syncEdge(true);
  }
}
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

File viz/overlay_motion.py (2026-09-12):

"""Clock alignment and attitude estimation for offline overlay rendering.

Quaternions are w,x,y,z, rotating sensor coordinates into a Z-up world.
No position or jump height is inferred from the IMU.
"""

from __future__ import annotations

import csv
import json
import math
from pathlib import Path

import numpy as np

G = 9.80665
MAX_GAP = 0.03


def read_jsonl(path):
    return [
        json.loads(line) for line in Path(path).read_text().splitlines() if line.strip()
    ]


def latest_labels(session, video):
    latest = {row["id"]: row for row in read_jsonl(Path(session) / "labels.jsonl")}
    return sorted(
        (r for r in latest.values() if r.get("video") == video),
        key=lambda r: r["start_s"],
    )


def latest_syncs(session, video):
    latest = {
        row["sync_id"]: row
        for row in read_jsonl(Path(session) / "video_sync.jsonl")
        if row.get("video") == video
    }
    return sorted(latest.values(), key=lambda row: row["t_s"])


def load_samples(path):
    with Path(path).open() as stream:
        data = np.array(
            [
                [float(row[k]) for k in ("t_s", "ax", "ay", "az", "gx", "gy", "gz")]
                for row in csv.DictReader(stream)
            ],
            dtype=float,
        )
    if (
        data.ndim != 2
        or len(data) < 2
        or not np.isfinite(data).all()
        or np.any(np.diff(data[:, 0]) <= 0)
    ):
        raise ValueError(
            "Samples must contain finite values and strictly increasing timestamps."
        )
    return data


def check_alignment(labels, scale, offset, coverage):
    for row in labels:
        for key, video_key in (("start_s", "video_start_s"), ("end_s", "video_end_s")):
            if not math.isclose(
                scale * row[video_key] + offset, row[key], rel_tol=0, abs_tol=1e-6
            ):
                raise ValueError(
                    f"Label {row['id']} has stale alignment. Review and save it again before rendering."
                )
        if not coverage[0] <= row["start_s"] < row["end_s"] <= coverage[1]:
            raise ValueError(
                f"Label {row['id']} extends outside recorded sensor samples."
            )


def qmul(a, b):
    w, x, y, z = a
    v, i, j, k = b
    return np.array(
        [
            w * v - x * i - y * j - z * k,
            w * i + x * v + y * k - z * j,
            w * j - x * k + y * v + z * i,
            w * k + x * j - y * i + z * v,
        ]
    )


def matrix(q):
    w, x, y, z = q
    return np.array(
        [
            [1 - 2 * (y * y + z * z), 2 * (x * y - w * z), 2 * (x * z + w * y)],
            [2 * (x * y + w * z), 1 - 2 * (x * x + z * z), 2 * (y * z - w * x)],
            [2 * (x * z - w * y), 2 * (y * z + w * x), 1 - 2 * (x * x + y * y)],
        ]
    )


def from_gravity(accel):
    norm = np.linalg.norm(accel)
    if norm < 1e-8:
        return np.array([1.0, 0.0, 0.0, 0.0])
    up = accel / norm
    if up[2] < -0.999999:
        return np.array([0.0, 1.0, 0.0, 0.0])
    q = np.array([1 + up[2], up[1], -up[0], 0.0])
    return q / np.linalg.norm(q)
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

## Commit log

2026-09-07 add fritzing and assets
    [skate-judge-direct-lipo.fz, skate-judge-direct-lipo.fzz]
2026-09-07 now with 3d printable enclosures
    [base-velcro.stl, base.stl, fit-coupon.stl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]
2026-09-08 fix for problems discovered after printing
    [base-velcro.stl, base.stl, fit-coupon.stl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]
2026-09-10 fix for bug on start, bump LED power to highest setting
    [imu_logger.ino, imu_stream.ino, onboard.py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]
2026-09-15 add DIN 7991 screw holes
    [lid.stl, skate-judge.scad]
2026-09-21 adding an external sd card for >5 min recording times
    [skate-judge-direct-lipo.fz, skate-judge-direct-lipo.fzz]
2026-09-25 show remaining battery and make sync pin changable in case some dummy solders the wrong one
    [imu_logger.ino, log_storage.h, onboard.py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]
2026-09-25 add resilience on write failure
    [imu_logger.ino, log_storage.h, log_writer.h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]
2026-09-27 update hardware enclosure to secure the sd card
    [base-velcro.stl, base.stl, sd-fit-base.stl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]
2026-10-03 now with press fittings
    [base-velcro.stl, base.stl, fit-coupon.stl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]
2026-10-10 adjust for temperature drifting clocks
2026-10-14 beef up posts for 3d printing and switch to flexible LED pcb
2026-10-25 better trick filtering
